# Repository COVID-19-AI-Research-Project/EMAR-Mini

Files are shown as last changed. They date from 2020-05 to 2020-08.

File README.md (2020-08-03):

# Peter Moss COVID-19 AI Research Project
## EMAR Mini Emergency Assistance Robot
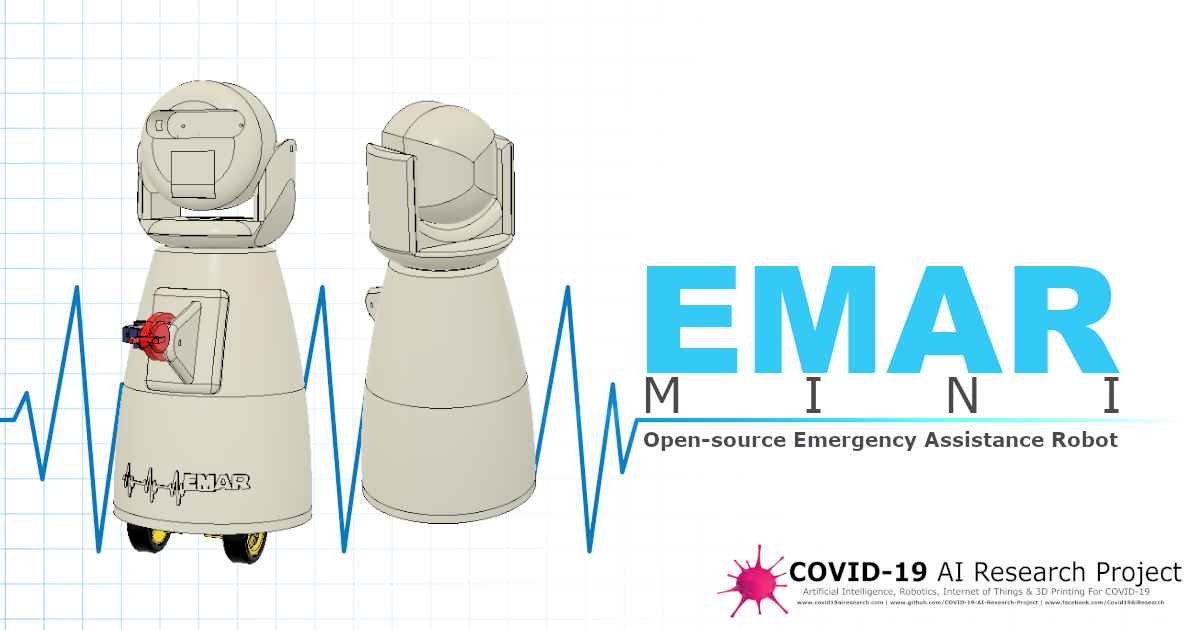
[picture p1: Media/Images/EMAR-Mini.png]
EMAR Mini Emergency Assistance Robot (https://github.com/COVID-19-AI-Research-Project/EMAR-Mini)


    

&nbsp; 

# Table Of Contents

- [Introduction](#introduction)
- [Open Technology](#open-technology)
- [Key Features](#key-features)
- [Available Features](#avialable-features)
- [About Raspberry Pi 4](#about-raspberry-pi-4)
- [About Intel® RealSense™ D415](#about-intel-realsense-d415)
- [About Intel® Neural Compute Stick 2](#about-intel-neural-compute-stick-2)
- [About ELEGOO UNO R3 Kit](#about-elegoo-uno-r3-kit)
- [About ESP8266 12F](#about-esp8266-12f)
- [Projects](#projects)
- [Contributing](#contributing)
    - [Contributors](#contributors)
- [Versioning](#versioning)
- [License](#license)
- [Bugs/Issues](#bugs-issues)

&nbsp;

# Introduction

EMAR Mini Emergency Assistance Robot

**EMAR Mini** is a minature version of EMAR, an open-source Emergency Robot Assistant to assist doctors, nurses and hospital staff during the COVID-19 pandemic, and similar situations we may face in the future.

The idea for this open-source tele-operated robot came as I was sat in room in a hospital surrounded by people with COVID-19 as a potential COVID-19 Pneumonia patient. The doctors, nurses and other teams were in among us for the whole 12 hours or more I was in the hospital.

Some of the common things I saw was nurses & doctors calling patients, giving paracetamol, taking temperatures, adjusting masks and blankets. Every time one of the medical staff had to do one of these tasks they were putting themselves in danger of catching COVID-19.

Each of these tasks can be carried out by tele-operated robots, so this is where the idea for EMAR came from.   

EMAR Mini will be our official demonstration robot as it is smaller and more portable, though has obvious restrictions compared to EMAR. EMAR Mini does not have the full capabilities of EMAR.

__This project is a work in progress, however our plan is to work with a local medical/health center or hospital to do a pilot project with EMAR (Large).__

&nbsp;

# Open Technology
- **Open Software** 
    - EMAR Mini's software is entirely open-source.
- **Open STLS** 
    - The STL files required to print EMAR are open-source.

&nbsp;

# Key Features

Below are the features that will be available in the completed 

- **HIAS Network Device:** EMAR is a device on the HIAS network, allowing machine to machine/machine to application communication.

- **HIAS UI Plugin:** Integration with the HIAS UI.

- **3D printed:** EMAR's shell is 3D printed.

- **Tele-Operated:** Remotely operated using the HIAS UI, voice control & remote control.

- **Real-Time Depth Sensing:**  Uses Intel® RealSense™ D415 camera and streams depth frames to a local server, used by HIAS to allow users to see realtime stream of depth sensors.

- **Real-Time Camera Stream:** Uses Intel® RealSense™ D415 camera and streams camera frames to a local server.

- **Object Detection:** Uses Intel Neural Computer Stick 2 to provide object recognition on the Realsense D415 camera stream.

- **Remote Control:** Uses ELEGOO Uno R3 kit with their IR Receiver Module and Remote Control to provide easy remote control of EMAR Mini.

- **Real-Time 2 Way Audio Communication:** Audio is sent from HIAS and other applications to EMAR Mini and vice versa. This feature is to provide medical teams the ability to communicate with patients in real-time whilst seeing them via the real-time camera stream.

- **Thermal Sensing:** A thermal camera is used to take patient's temperatures safely.

&nbsp;

# Available Features

As mentioned the project is a work in progress. Below you will find the currently available features.

- V1 of the 3D printed files are now available.

- V1 of the HIAS EMAR/EMAR Mini UI is now available in the [HIAS server](https://github.com/LeukemiaAiResearch/HIAS "HIAS server") project. This system allows tele-operation of EMAR Mini and viewing the real-time streams.

- HIAS tele-operation for the following:
    - Panning the head.
    - Moving the two arm pieces.

- Real-time depth sensing and stream.

- Real-time camera stream, object detection and object distance measurements.

&nbsp;

# About Raspberry Pi 4

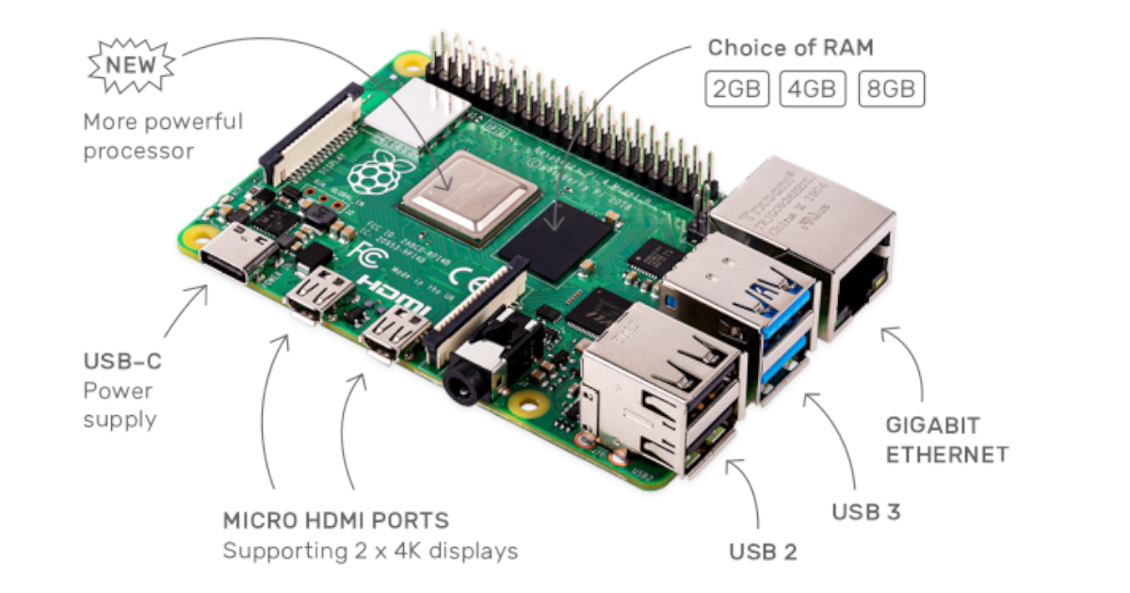
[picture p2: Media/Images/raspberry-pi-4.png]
Raspberry Pi 4 (https://www.raspberrypi.org/products/raspberry-pi-4-model-b/)


The [Rapsberry Pi 4](https://www.raspberrypi.org/products/raspberry-pi-4-model-b/ "Rapsberry Pi 4") is the latest model in the Raspberry Pi family. The new model is more energey efficient, provides Gigabit Ethernet/WiFi/Bluetooth and has USB3. You can choose from 2GB, 4GB, or 8GB ram depending on the requirements of your project. 

In this project we use the 2GB ram model and the [Rapsberry Pi OS (Buster)](https://www.raspberrypi.org/downloads/raspberry-pi-os/ "Rapsberry Pi OS (Buster)"). The RPI4 device homes all of the software required to run EMAR Mini.

&nbsp;

# About Intel® RealSense™ D415

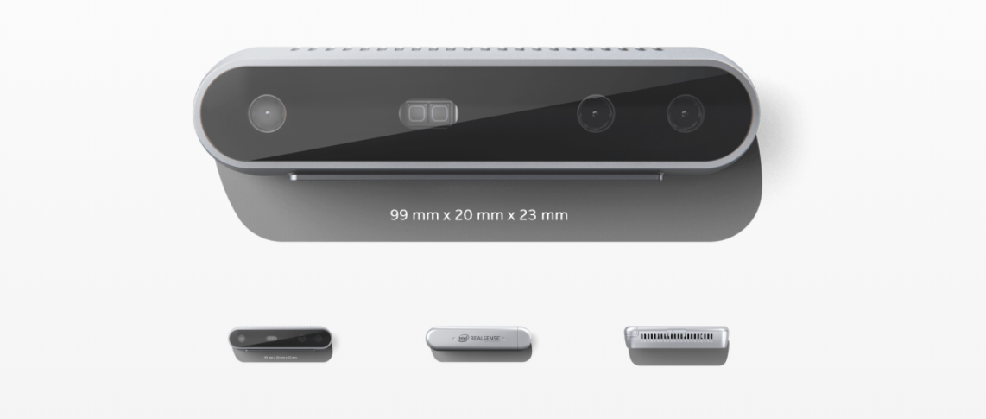
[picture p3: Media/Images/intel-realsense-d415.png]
Intel® RealSense™ D415 (https://www.intelrealsense.com/depth-camera-d415/)


The [Intel® RealSense™ D415](https://www.intelrealsense.com/depth-camera-d415/ "Intel® RealSense™ D415") has a standard field of view well suited for high accuracy applications such as 3D scanning. With a rolling shutter on the depth sensor, the D415 offers our highest depth quality per degree. 

In this project we use the D415 device to provide real-time depth and camera streams, as well as providing the depth measurements to allow distance measuring of objects seen by the camera.

&nbsp;

# About Intel® Neural Compute Stick 2

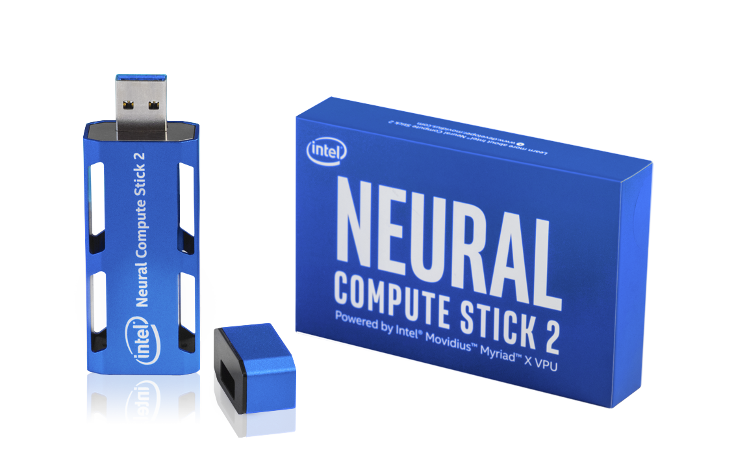
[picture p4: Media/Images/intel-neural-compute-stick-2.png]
Intel® Neural Compute Stick 2 (https://store.intelrealsense.com/buy-intel-neural-compute-stick-2.html)


The [Intel® Neural Compute Stick 2](https://store.intelrealsense.com/buy-intel-neural-compute-stick-2.html "Intel® Neural Compute Stick 2") (NCS2) is a USB plug & play AI device for deep learning inference at the edge. The Intel® NCS2 is built on the Intel® Movidius™ Myriad™ X VPU featuring 16 programmable shave cores and a dedicated neural compute engine for hardware acceleration of deep neural network inferences. 

In this project we use the NCS2 device to provide real-time object detection on the D415 real-time camera stream.

&nbsp;

# About ELEGOO UNO R3 Kit

ELEGOO UNO R3 EMAR Mini Remote Control (https://www.amazon.es/ELEGOO-Iniciaci%C3%B3n-Alimentaci%C3%B3n-Servomotor-Desarrollo/dp/B01MXGST4I)

 The [ELEGOO UNO Project Super Starter Kit](https://www.amazon.es/ELEGOO-Iniciaci%C3%B3n-Alimentaci%C3%B3n-Servomotor-Desarrollo/dp/B01MXGST4I "ELEGOO UNO Project Super Starter Kit") is an IoT development kit that provides an **ELEGOO UNO R3** board which is compatible with Arduino IDE, and a range of IoT sensors and actuators for fast prototyping of IoT projects. 

 In this project we use the **IR Receiver Module** and **Remote Control** to provide real-time control of EMAR Mini. 

 **We would like to thank ELEGOO for sponsoring us with this kit. This will be one of the medical projects we are building that will use this kit.**

 # About ESP8266 12F

 The [ESP8266 12F](https://www.espressif.com/en/products/socs/esp8266/overview "ESP8266 12F") a 2016 chip from the ESP8266 family. The chip has 1 MiB of built-in flash, allowing the building of single-chip devices capable of connecting to Wi-Fi.

 We use the ESP8266 12F to connect the ELEGOO UNO R3 to the iotJumpWay allowing communication between the remote control and EMAR Mini. The ELEGOO UNO R3 communicates with the ESP8266 via serial communication which sends commands to EMAR Mini via the iotJumpWay

&nbsp;

## Projects

Below you will find all EMAR Mini projects, including the STLs for 3D printing, the Raspberry Pi 4 version, and the remote control.

**PLEASE NOTE: This project requires a functioning installation of the [HIAS server](https://github.com/LeukemiaAiResearch/HIAS "HIAS server"). Follow the [HIAS server installation guide](https://github.com/LeukemiaAiResearch/HIAS/blob/master/Documentation/Installation/Installation.md "HIAS server installation guide") before beginning these tutorials.**

| ID | GUIDE | INFORMATION | AUTHOR | Status |
| ----- | ----- | --- | --- | --- |
| 1 | [STLs For 3D Printing](Projects/STLs "STLs For 3D Printing") | V1 of the open-source 3D printed files for EMAR Mini. |  [Jose Mario Garza](https://www.leukemiaresearchassociation.ai/team/jose-mario-garza "Jose Mario Garza") | V1 Complete | 
| 2 | [Raspberry Pi 4](Projects/RPI4 "Raspberry Pi 4") | V1 of the Raspberry Pi 4 hardware and software setup required for EMAR Mini. |  [Adam Milton-Barker](https://www.leukemiaresearchassociation.ai.com/team/adam-milton-barker "Adam Milton-Barker") | V1 Complete | 
| 3 | [ELEGOO UNO R3 Remote Control](Projects/Remote-Control "ELEGOO UNO R3 Remote Control") | An IoT connected remote control that can control EMAR Mini. |  [Adam Milton-Barker](https://www.leukemiaresearchassociation.ai.com/team/adam-milton-barker "Adam Milton-Barker") | Complete | 

&nbsp;

# Contributing

The Peter Moss Acute COVID-19 AI Research project encourages and welcomes code contributions, bug fixes and enhancements from the Github.

Please read the [CONTRIBUTING](CONTRIBUTING.md "CONTRIBUTING") document for a full guide to forking your repositories and submitting your pull requests. You will also find information about your code of conduct on this page.

## Contributors

- [Adam Milton-Barker](https://www.leukemiaresearchassociation.ai/team/adam-milton-barker "Adam Milton-Barker") - [Asociacion De Investigation En Inteligencia Artificial Para La Leucemia Peter Moss](https://www.leukemiaresearchassociation.ai "Asociacion De Investigation En Inteligencia Artificial Para La Leucemia Peter Moss") President & Lead Developer, Sabadell, Spain

- [Jose Mario Garza](https://www.leukemiaresearchassociation.ai/team/jose-mario-garza "Jose Mario Garza") - [Asociacion De Investigation En Inteligencia Artificial Para La Leucemia Peter Moss](https://www.leukemiaresearchassociation.ai "Asociacion De Investigation En Inteligencia Artificial Para La Leucemia Peter Moss") 3D Designer/Printer, Mexico

&nbsp;

# Versioning

We use SemVer for versioning. For the versions available, see [Releases](releases "Releases").

&nbsp;

# License

This project is licensed under the **MIT License** - see the [LICENSE](LICENSE "LICENSE") file for details.

&nbsp;

# Bugs/Issues

We use the [repo issues](issues "repo issues") to track bugs and general requests related to using this project. See [CONTRIBUTING](CONTRIBUTING.md "CONTRIBUTING") for more info on how to submit bugs, feature requests and proposals.

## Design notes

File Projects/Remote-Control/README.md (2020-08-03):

# Peter Moss COVID-19 AI Research Project
## EMAR Mini Emergency Assistance Robot
### ELEGOO UNO R3 Remote Control
EMAR Mini Emergency Assistance Robot (https://github.com/COVID-19-AI-Research-Project/EMAR-Mini)

&nbsp; 

# Table Of Contents

- [Introduction](#introduction)
- [Installation](#installation)
- [Start The Software](#start-the-software)
- [Use the remote control](#use-the-remote-control)
- [Contributing](#contributing)
    - [Contributors](#contributors)
- [Versioning](#versioning)
- [License](#license)
- [Bugs/Issues](#bugs-issues)

&nbsp;

# Introduction

Remote Control

 In this project we use the **ELEGOO UNO R3** with their **IR Receiver Module** and **Remote Control** from their [ELEGOO UNO Project Super Starter Kit](https://www.amazon.es/ELEGOO-Iniciaci%C3%B3n-Alimentaci%C3%B3n-Servomotor-Desarrollo/dp/B01MXGST4I "ELEGOO UNO Project Super Starter Kit") to provide real-time control of EMAR Mini. 

 **We would like to thank ELEGOO for sponsoring us with this kit. This will be one of the medical projects we are building that will use this kit.**

 For WiFi connectivity we use the ESP8266 12f and serial communication to receive the IR commands from the ELEGOO board.

&nbsp;

# Installation

Please follow the [Installation Guide](Documentation/Installation.md) to install the EMAR Mini software and hardware.

&nbsp;

# Use the remote control

Now you are all setup, just plug your ELEGOO UNO R3 board into the mains, make sure EMAR Mini is alive, point the remote at the IR sensor and use the following buttons to control EMAR Mini.

- Fast Forward (>>) = Pan head right
- Rewind (<<) - Pan head left
- Pause = Pan head to center

- 2 = Arm section 1 up
- 5 = Arm section 1 down
- Volume Up (^) = Arm section 2 up
- Volume Down = Arm section 2 down

These actions should happen in near real-time. 

# To Be Continued

HIAS EMAR UI

We are working on modifications to the 3D printed files and the additional functionality such as head tilt and wheels. Keep an eye on our page for updates to this repository.

&nbsp;

# Contributing

The Peter Moss Acute COVID-19 AI Research project encourages and welcomes code contributions, bug fixes and enhancements from the Github.

Please read the [CONTRIBUTING](../../CONTRIBUTING.md "CONTRIBUTING") document for a full guide to forking your repositories and submitting your pull requests. You will also find information about your code of conduct on this page.

## Contributors

- [Adam Milton-Barker](https://www.leukemiaresearchassociation.ai/team/adam-milton-barker "Adam Milton-Barker") - [Asociacion De Investigation En Inteligencia Artificial Para La Leucemia Peter Moss](https://www.leukemiaresearchassociation.ai "Asociacion De Investigation En Inteligencia Artificial Para La Leucemia Peter Moss") President & Lead Developer, Sabadell, Spain

&nbsp;

# Versioning

We use SemVer for versioning. For the versions available, see [Releases](../../releases "Releases").

&nbsp;

# License

This project is licensed under the **MIT License** - see the [LICENSE](../../LICENSE "LICENSE") file for details.

&nbsp;

# Bugs/Issues

We use the [repo issues](../../issues "repo issues") to track bugs and general requests related to using this project. See [CONTRIBUTING](../../CONTRIBUTING.md "CONTRIBUTING") for more info on how to submit bugs, feature requests and proposals.

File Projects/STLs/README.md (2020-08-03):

# Peter Moss COVID-19 AI Research Project
## EMAR Mini Emergency Assistance Robot
### STLs For 3D Printing
EMAR Mini Emergency Assistance Robot (https://github.com/COVID-19-AI-Research-Project/EMAR-Mini)

&nbsp; 

# Table Of Contents

- [Introduction](#introduction)
- [Prerequisites](#prerequisites)
  - [Clone the repository](#clone-the-repository)
      - [Developer Forks](#developer-forks)
- [Start Printing](#start-printing)
- [Contributing](#contributing)
    - [Contributors](#contributors)
- [Versioning](#versioning)
- [License](#license)
- [Bugs/Issues](#bugs-issues)

&nbsp;

# Introduction

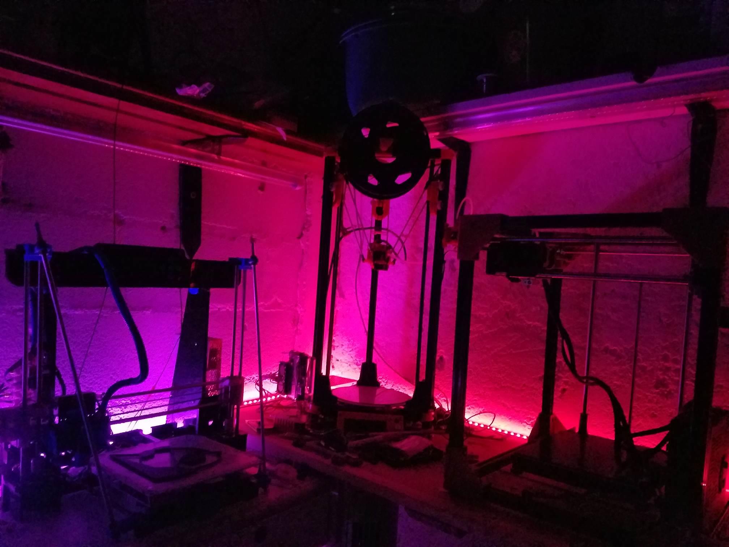
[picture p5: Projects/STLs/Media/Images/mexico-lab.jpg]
Mexico Lab


This tutorial will prepare you for printing your very on EMAR Mini V1. 
The STLs provided have been created by team member [Jose Mario Garza](https://www.leukemiaresearchassociation.ai/team/jose-mario-garza "Jose Mario Garza"), he also printed our version of EMAR Mini in his lab in Mexico.

__This project is a work in progress, we are in the process of modifying the STLs to allow for full functionality.__

&nbsp;

# Prerequisites

Before you can print your EMAR Mini V1, there are some prerequisites.

## Clone the repository

Clone the [EMAR-Mini](https://github.com/COVID-19-AI-Research-Project/EMAR-Mini " EMAR-Mini") repository from the [Peter Moss COVID-19 AI Research](https://github.com/COVID-19-AI-Research-Project "Peter Moss COVID-19 AI Research") Github Organization.

To clone the repository and install the COVID-19 Tensorflow DenseNet Classifier For Raspberry Pi 4, make sure you have Git installed. Now navigate to the home directory on your device using terminal/commandline, and then use the following command.

```
$ git clone https://github.com/COVID-19-AI-Research-Project/EMAR-Mini.git
```

Once you have used the command above you will see a directory called **EMAR-Mini** in your home directory.

```
ls
```

Using the ls command in your home directory should show you the following.

```
EMAR-Mini
```

Navigate to **COVID-19-AI-Research-Project/Projects/STLs** directory, this is your project root directory for this tutorial.

### Developer Forks

Developers from the Github community that would like to contribute to the development of this project should first create a fork, and clone that repository. For detailed information please view the [CONTRIBUTING](../../../../CONTRIBUTING.md "CONTRIBUTING") guide. You should pull the latest code from the development branch.

```
  $ git clone -b "0.5.0" https://github.com/COVID-19-AI-Research-Project/EMAR-Mini.git
```

The **-b "0.5.0"** parameter ensures you get the code from the latest master branch. Before using the below command please check our latest master branch in the button at the top of the project README.

&nbsp;

# Start Printing

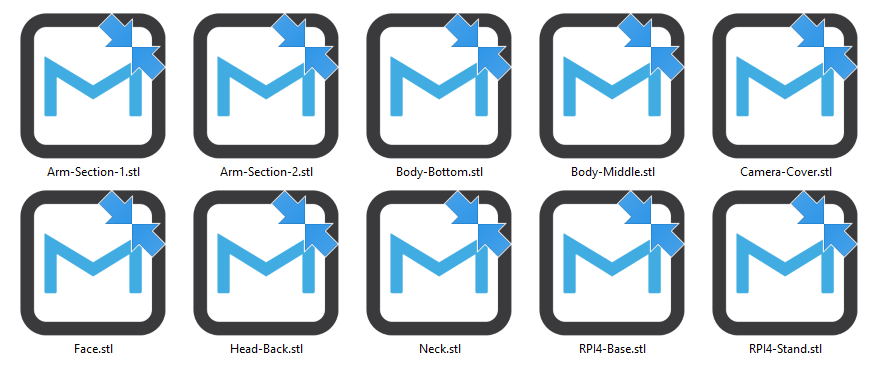
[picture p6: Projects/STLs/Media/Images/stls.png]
Start Printing


Now it is time to start printing, simply start printing the files from the **Files** folder.

&nbsp;

# Contributing

The Peter Moss Acute COVID-19 AI Research project encourages and welcomes code contributions, bug fixes and enhancements from the Github.

Please read the [CONTRIBUTING](../../CONTRIBUTING.md "CONTRIBUTING") document for a full guide to forking your repositories and submitting your pull requests. You will also find information about your code of conduct on this page.

## Contributors

- [Jose Mario Garza](https://www.leukemiaresearchassociation.ai/team/jose-mario-garza "Jose Mario Garza") - [Asociacion De Investigation En Inteligencia Artificial Para La Leucemia Peter Moss](https://www.leukemiaresearchassociation.ai "Asociacion De Investigation En Inteligencia Artificial Para La Leucemia Peter Moss") 3D Designer/Printer, Mexico

&nbsp;

# Versioning

We use SemVer for versioning. For the versions available, see [Releases](../../releases "Releases").

&nbsp;

# License

This project is licensed under the **MIT License** - see the [LICENSE](../../LICENSE "LICENSE") file for details.

&nbsp;

# Bugs/Issues

We use the [repo issues](../../issues "repo issues") to track bugs and general requests related to using this project. See [CONTRIBUTING](../../CONTRIBUTING.md "CONTRIBUTING") for more info on how to submit bugs, feature requests and proposals.

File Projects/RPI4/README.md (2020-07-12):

# Peter Moss COVID-19 AI Research Project
## EMAR Mini Emergency Assistance Robot
### Raspberry Pi 4
EMAR Mini Emergency Assistance Robot (https://github.com/COVID-19-AI-Research-Project/EMAR-Mini)

&nbsp; 

# Table Of Contents

- [Introduction](#introduction)
- [Installation](#installation)
- [Start The Software](#start-the-software)
- [HIAS EMAR UI](#hias-emar-ui)
- [To Be Continued](#to-be-continued)
- [Contributing](#contributing)
    - [Contributors](#contributors)
- [Versioning](#versioning)
- [License](#license)
- [Bugs/Issues](#bugs-issues)

&nbsp;

# Introduction

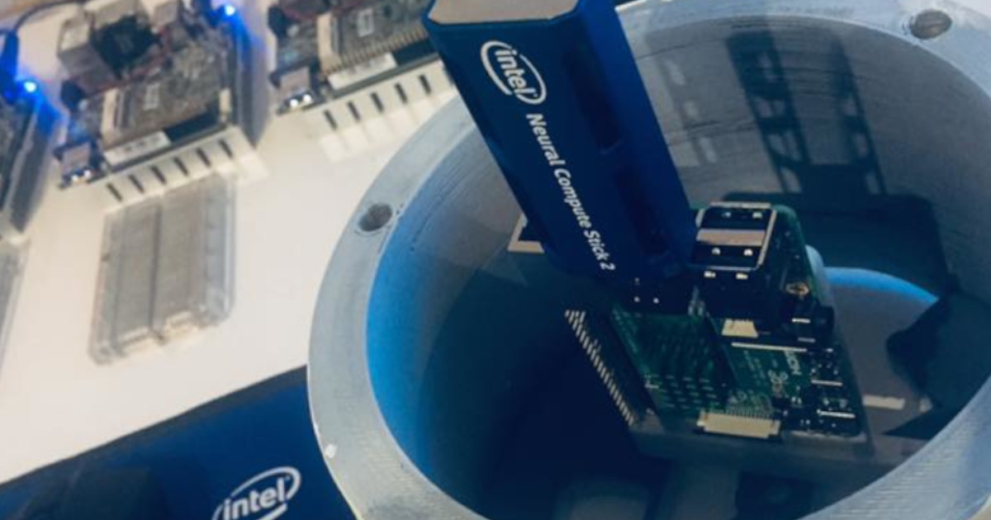
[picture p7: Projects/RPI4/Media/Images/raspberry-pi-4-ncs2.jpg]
Raspberry Pi 4


The Raspberry Pi 4 homes the EMAR Mini software and powers the Intel hardware. This guide will provide a link to the installation guide and steps to get your EMAR Mini up and running using the HIAS Server UI. 

__This project is a work in progress, we are in the process of completing for full functionality of EMAR Mini.__

&nbsp;

# Installation

Please follow the [Installation Guide](Documentation/Installation.md) to install the EMAR Mini software and hardware.

&nbsp;

# Start The Software

You now need to start the EMAR Mini software. On your Raspberry Pi navigate to your project root and issue the following command:

```
python3 EMAR.py
```

EMAR Mini will connect to your HIAS iotJumpWay broker, and start the Realsense stream and classifier.

# HIAS EMAR UI

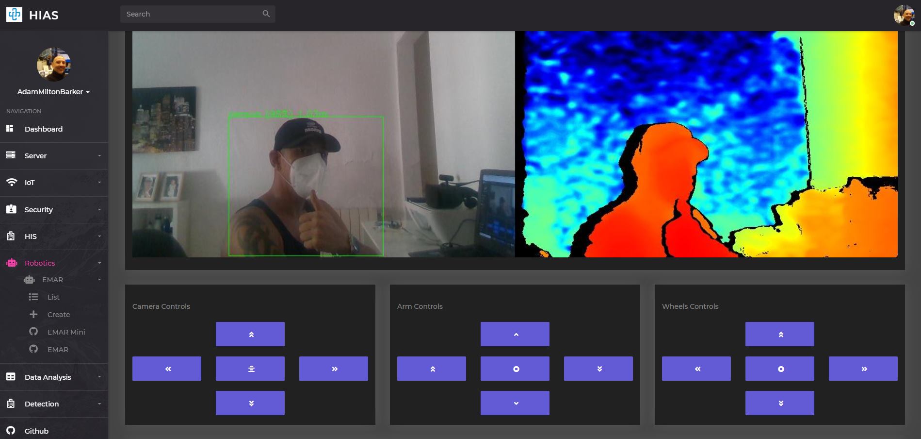
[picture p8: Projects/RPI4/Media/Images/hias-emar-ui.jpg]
HIAS EMAR UI


Now head to your HIAS Server and navigate to **Robotics->EMAR->List**, select your EMAR device and you should see your camera stream and the controls for EMAR Mini.

Available controls in this version of EMAR Mini are as follows:

- Head
  - LEFT
  - CENTER
  - RIGHT

  As you pan the head, you should see your camera stream moving in near real-time in the HIAS Server EMAR UI.

- Arm 
  - Arm section 1 UP
  - Arm section 1 DOWN
  - Arm section 2 UP
  - Arm section 2 DOWN

  In the **Arm** section, the double arrows represent arm section 1 and the single arrows represent arm section 2.

These actions should happen in near real-time, even if the controller is on the other side of the world. 

The object detection will detect any of the objects from the list in the project configuration, and will calculate the distance from EMAR Mini using the depth readings from the Intel Realsense. 

# To Be Continued

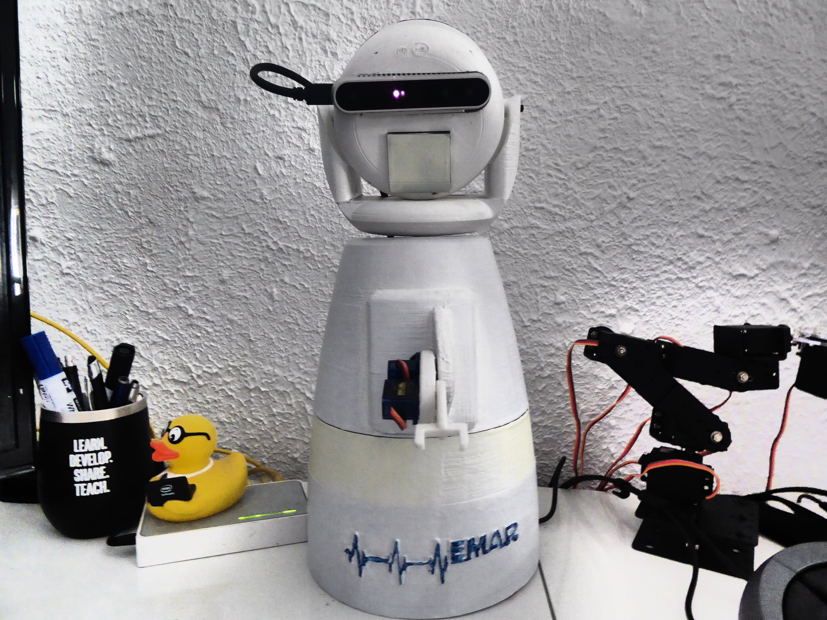
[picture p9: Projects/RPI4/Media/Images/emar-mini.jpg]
HIAS EMAR UI


We are working on modifications to the 3D printed files and the additional functionality such as head tilt and wheels. Keep an eye on our page for updates to this repository.

&nbsp;

# Contributing

The Peter Moss Acute COVID-19 AI Research project encourages and welcomes code contributions, bug fixes and enhancements from the Github.

Please read the [CONTRIBUTING](../../CONTRIBUTING.md "CONTRIBUTING") document for a full guide to forking your repositories and submitting your pull requests. You will also find information about your code of conduct on this page.

## Contributors

- [Adam Milton-Barker](https://www.leukemiaresearchassociation.ai/team/adam-milton-barker "Adam Milton-Barker") - [Asociacion De Investigation En Inteligencia Artificial Para La Leucemia Peter Moss](https://www.leukemiaresearchassociation.ai "Asociacion De Investigation En Inteligencia Artificial Para La Leucemia Peter Moss") President & Lead Developer, Sabadell, Spain

- [Jose Mario Garza](https://www.leukemiaresearchassociation.ai/team/jose-mario-garza "Jose Mario Garza") - [Asociacion De Investigation En Inteligencia Artificial Para La Leucemia Peter Moss](https://www.leukemiaresearchassociation.ai "Asociacion De Investigation En Inteligencia Artificial Para La Leucemia Peter Moss") 3D Designer/Printer, Mexico

&nbsp;

# Versioning

We use SemVer for versioning. For the versions available, see [Releases](../../releases "Releases").

&nbsp;

# License

This project is licensed under the **MIT License** - see the [LICENSE](../../LICENSE "LICENSE") file for details.

&nbsp;

# Bugs/Issues

We use the [repo issues](../../issues "repo issues") to track bugs and general requests related to using this project. See [CONTRIBUTING](../../CONTRIBUTING.md "CONTRIBUTING") for more info on how to submit bugs, feature requests and proposals.

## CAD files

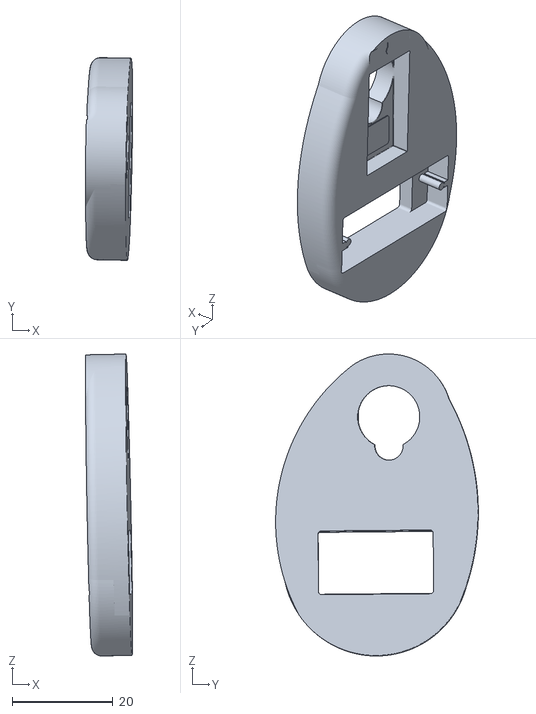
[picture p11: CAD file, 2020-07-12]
Projects/STLs/Files/Arm-Section-1.stl
9.43 x 40.3 x 60.0

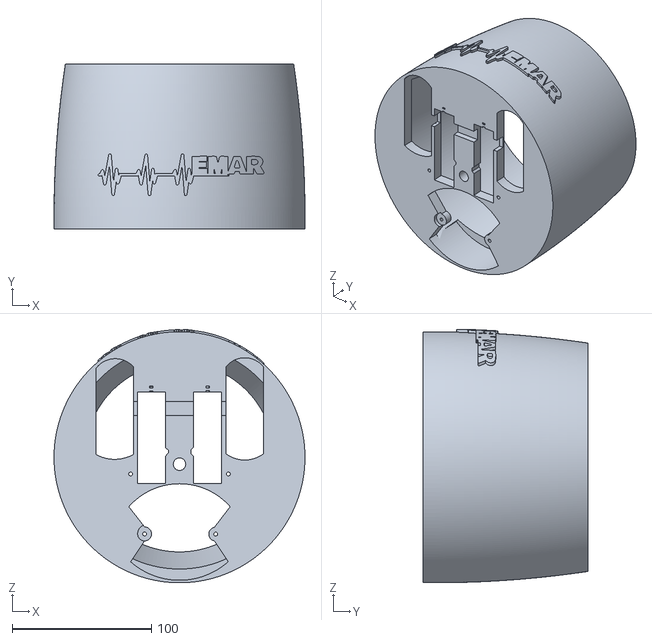
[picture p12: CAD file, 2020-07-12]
Projects/STLs/Files/Body-Bottom.stl
180.0 x 118.1 x 181.8

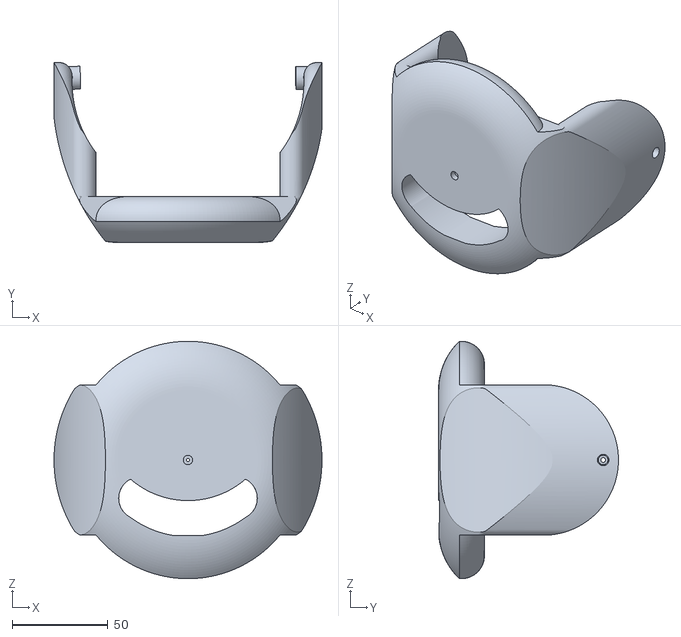
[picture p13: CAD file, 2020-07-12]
Projects/STLs/Files/Neck.stl
140.0 x 94.0 x 124.0

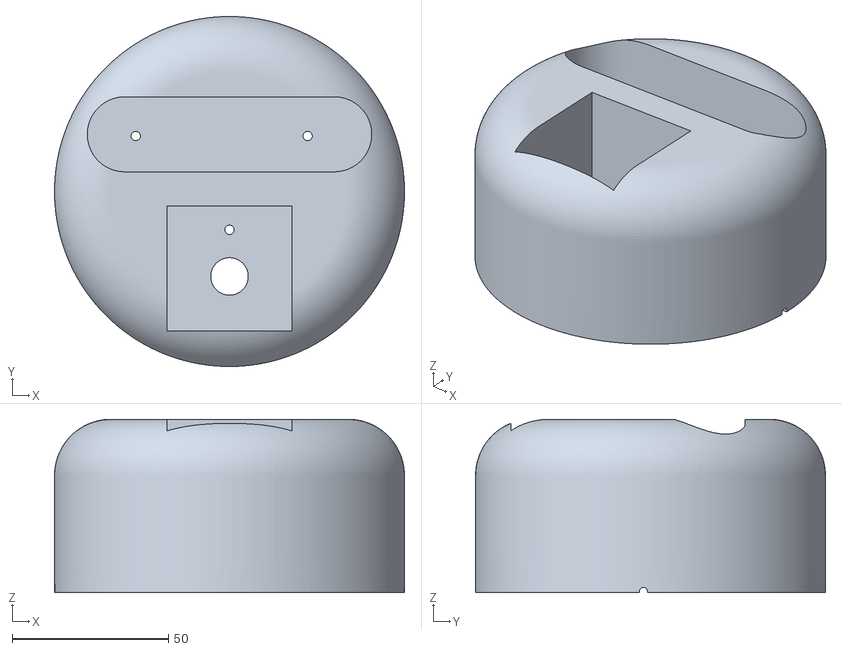
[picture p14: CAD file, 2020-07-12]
Projects/STLs/Files/Face.stl
112.0 x 112.0 x 55.5

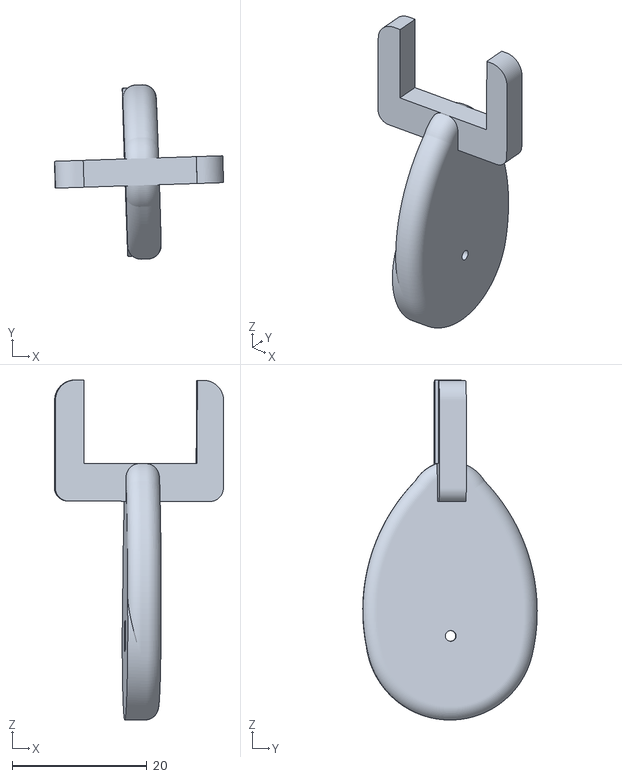
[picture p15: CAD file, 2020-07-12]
Projects/STLs/Files/Arm-Section-2.stl
25.2 x 25.9 x 50.5

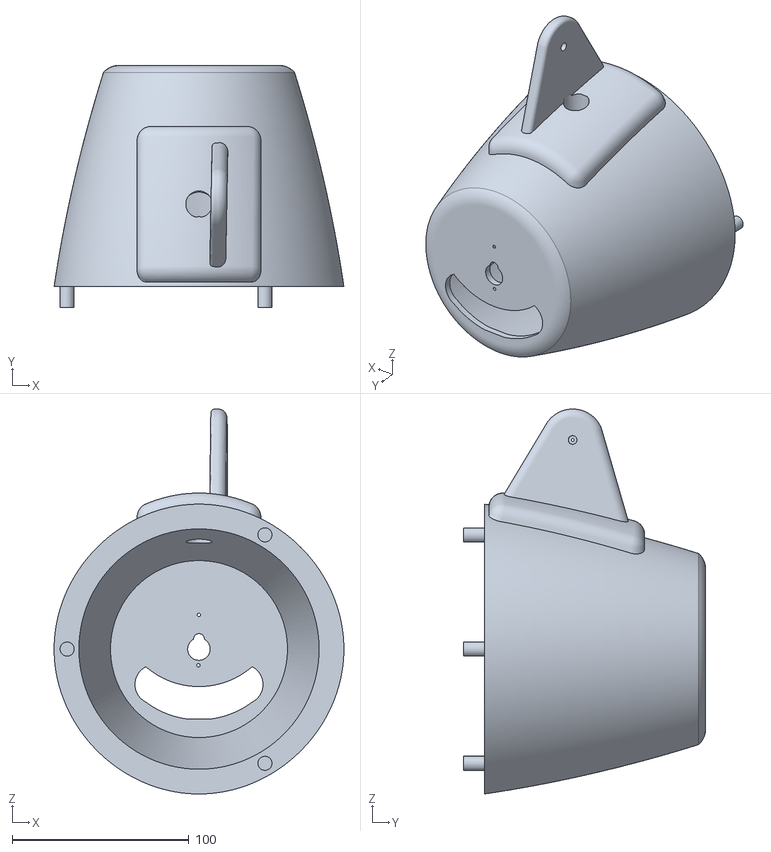
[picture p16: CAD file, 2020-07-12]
Projects/STLs/Files/Body-Middle.stl
163.8 x 137.0 x 217.6

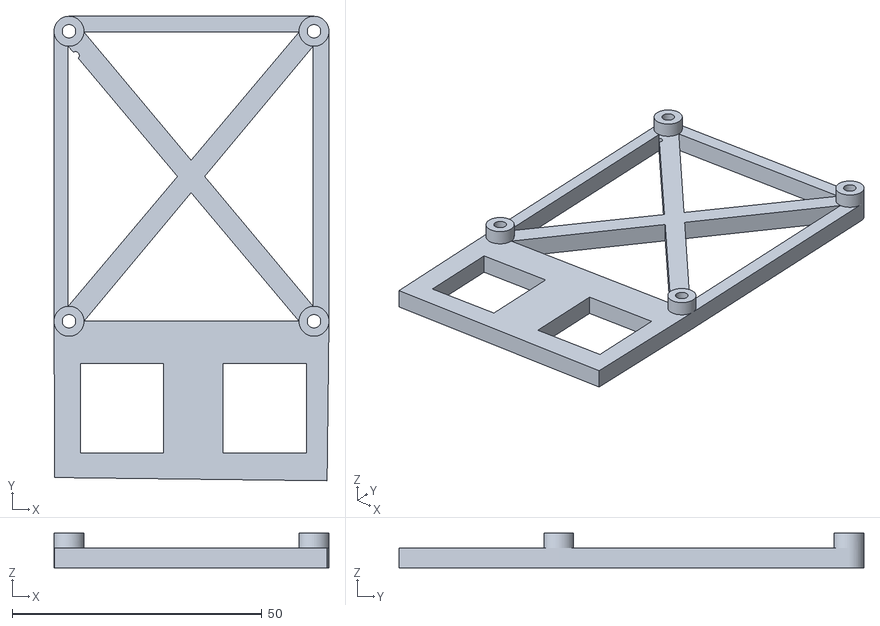
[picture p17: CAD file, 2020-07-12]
Projects/STLs/Files/RPI4-Stand.stl
55.0 x 92.9 x 7.00

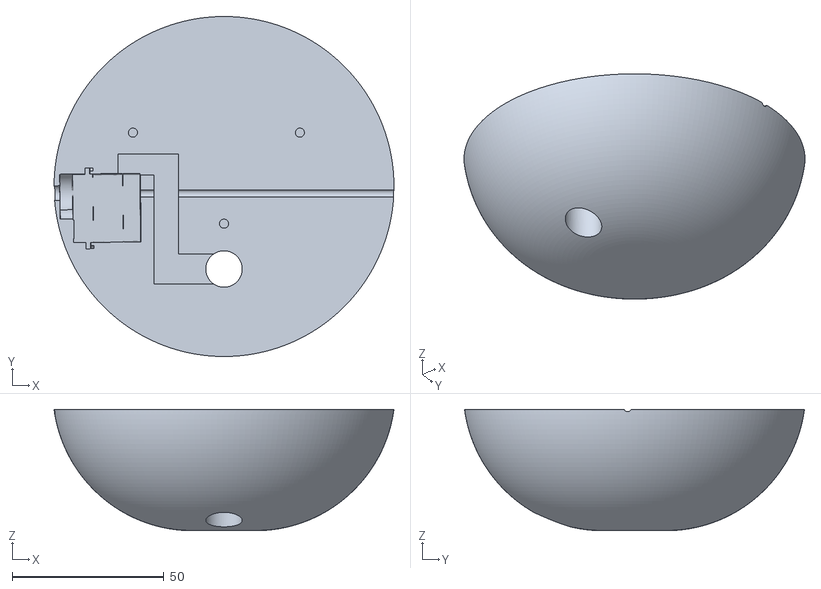
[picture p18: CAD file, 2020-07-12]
Projects/STLs/Files/Head-Back.stl
112.0 x 112.0 x 40.0

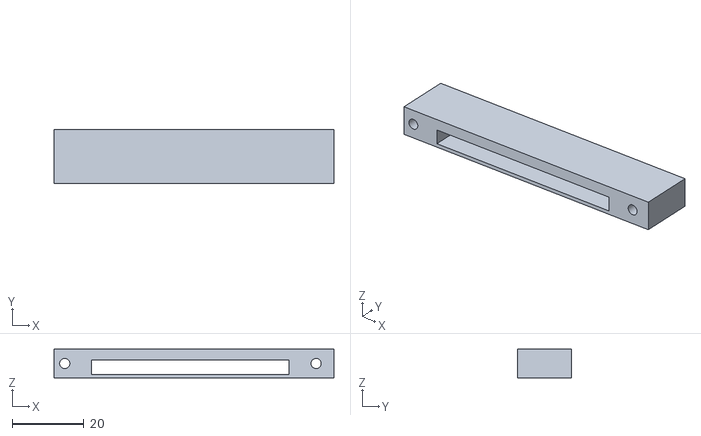
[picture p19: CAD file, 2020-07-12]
Projects/STLs/Files/RPI4-Base.stl
78.0 x 15.0 x 8.00

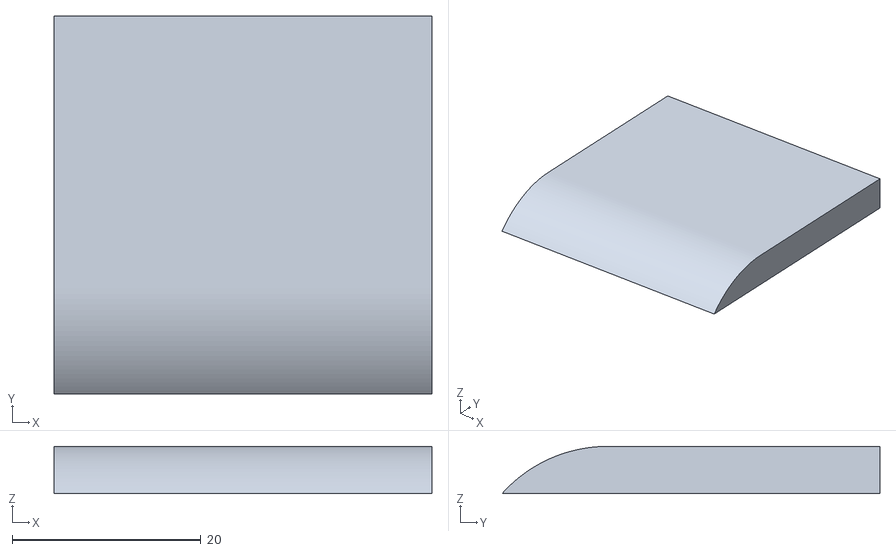
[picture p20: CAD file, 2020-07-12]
Projects/STLs/Files/Camera-Cover.stl
40.0 x 40.0 x 5.00

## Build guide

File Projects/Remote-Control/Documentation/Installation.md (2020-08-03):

# Peter Moss COVID-19 AI Research Project
## EMAR Mini Emergency Assistance Robot
EMAR Emergency Assistance Robot (https://github.com/COVID-19-Research-Project/EMAR-Mini)

&nbsp;

# Table Of Contents

- [Introduction](#introduction)
- [DISCLAIMER](#disclaimer)
- [V1 Required Hardware](#v1-required-hardware)
- [Prerequisites](#prerequisites)
    - [HIAS - Hospital Intelligent Automation System](#hias-hospital-intelligent-automation-system)
    - [STLs For 3D Printing Tutorial](#stls-for-3d-printing-tutorial)
    - [Raspberry Pi 4 Tutorial](#raspberry-pi-4-tutorial)
- [Installation](#installation)
    - [ESP8266 12F](#esp8266-12f)
    - [ELEGOO UNO R3 & Breadboard](#elegoo-uno-r3--breadboard)
    - [iotJumpWay Credentials](#iotjumpway-credentials)
    - [EMAR-RCP](#emar-rcp)
    - [EMAR-RCR](#emar-rcr)
- [Continue](#continue)
- [Contributing](#contributing)
    - [Contributors](#contributors)
- [Versioning](#versioning)
- [License](#license)
- [Bugs/Issues](#bugs-issues)

&nbsp;

# Introduction
The following guide will take you through setting up and installing [EMAR Mini Emergency Assistance Robot](https://github.com/COVID-19-Research-Project/EMAR-Mini "EMAR Mini Emergency Assistance Robot"). 

The Raspberry Pi 4 homes the EMAR Mini software and powers the Intel hardware.

&nbsp;

# DISCLAIMER

You should always be very careful when working with electronics! We will not accept responsibility for any damages done to hardware or yourself through full or partial use of this tutorial. Use this tutorial at your own risk, and take measures to ensure your own safety.

&nbsp;

# V1 Required Hardware

- 1 x ELEGOO UNO R3 Remote Control 
- 1 x ELEGOO IR Receiver Module
- 1 x Breadboard
- 1 x ESP8266
- 1 x USB to serial TTL UART Module
- 2 x Push Buttons
- 1 x 100Uf Ceramic Capacitor
- 5 x 10k Resistors
- 1 x Soldering Iron
- Solder
- Jumper wires

&nbsp;

# Prerequisites

Before you can complete this tutorial there are some prerequisites.

## HIAS - Hospital Intelligent Automation System
You will need a full installation of the [HIAS server](https://github.com/LeukemiaAiResearch/HIAS) to use the full functionality of this project. You can use this project with a 3rd party IoT broker if you like but we do not provide the documentation for that.

## STLs For 3D Printing Tutorial
You need to have completed the [STLs For 3D Printing](../../STLs "STLs For 3D Printing") tutorial and printed the EMAR Mini parts. 

## Raspberry Pi 4 Tutorial
You need to have completed the [Raspberry Pi 4](../../RPI4 "Raspberry Pi 4") tutorial and setup your EMAR Mini.

&nbsp;

# Installation
Now you will create your EMAR Mini Remote Control.

## ESP8266 12F
ESP8266 12F

First we will start with the ESP8266 12F. To start, heat up your soldering iron. Next you need to solder wires to the following pins:

- TXD0
- RXD0
- GPIO0
- GPIO2
- GPIO15
- GND
- VCC 
- RST
- EN

In addition you need to solder the capacitor bridging between GND & VCC.

You are now ready to move on to setting up your ELEGOO UNO R3 and breadboard.

## ELEGOO UNO R3 & Breadboard
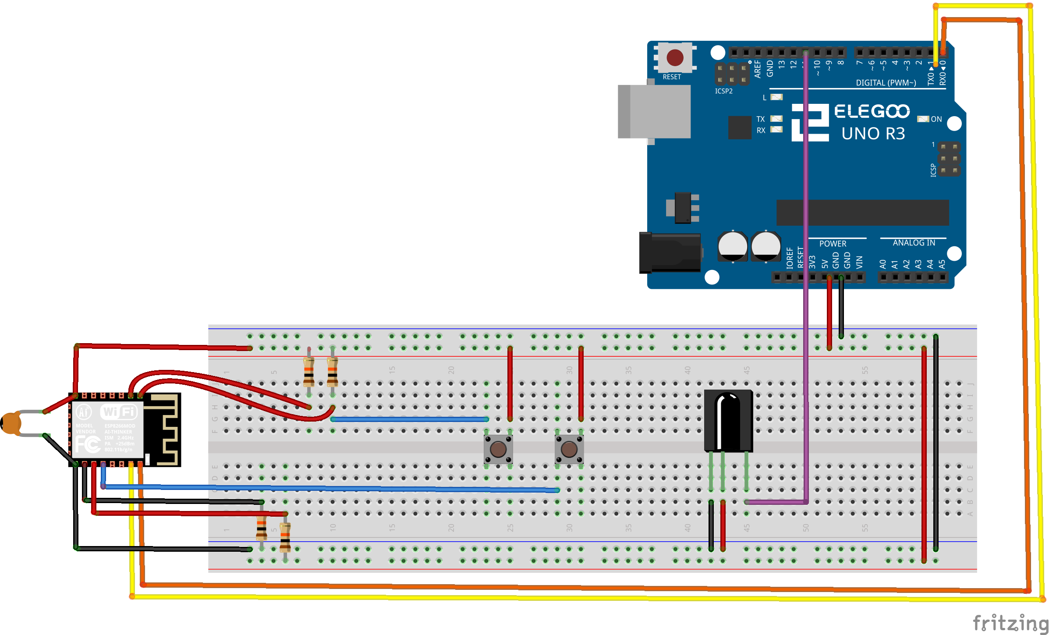
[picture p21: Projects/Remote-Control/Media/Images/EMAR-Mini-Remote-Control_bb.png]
ELEGOO UNO R3 & Breadboard


Follow the breadboard diagram above to set up your circuit. Here we are powering the ESP8266 directly from the 5V out of the ELEGOO UNO. As we are using the ESP8266, battery operation will not be possible as it will drain very quickly. You will need to plug your ELEGOO UNO into the mains using a suitable power adapter.

**WARNING: Many will advise not to power ESP8266 with 5V, however in my experience it is the only way that ESP8266 will work correctly with SSL. It is advised that the ESP8266 is not designed to run at 5V, however running at 3V you will more than likely not be able to make this project work. In all the years I have been using ESP8266, I have never had an issue with a single chip powering it with 5V. You should use 5V at your own discression**

The ESP8266 is used for WiFi communication, it connects to the iotJumpWay and waits for activity from the IR sensor, when it receives commands it sends via the iotJumpWay to EMAR Mini which allows you to control the robot using the remote control.

ELEGOO UNO R3 & Breadboard

## iotJumpWay Credentials
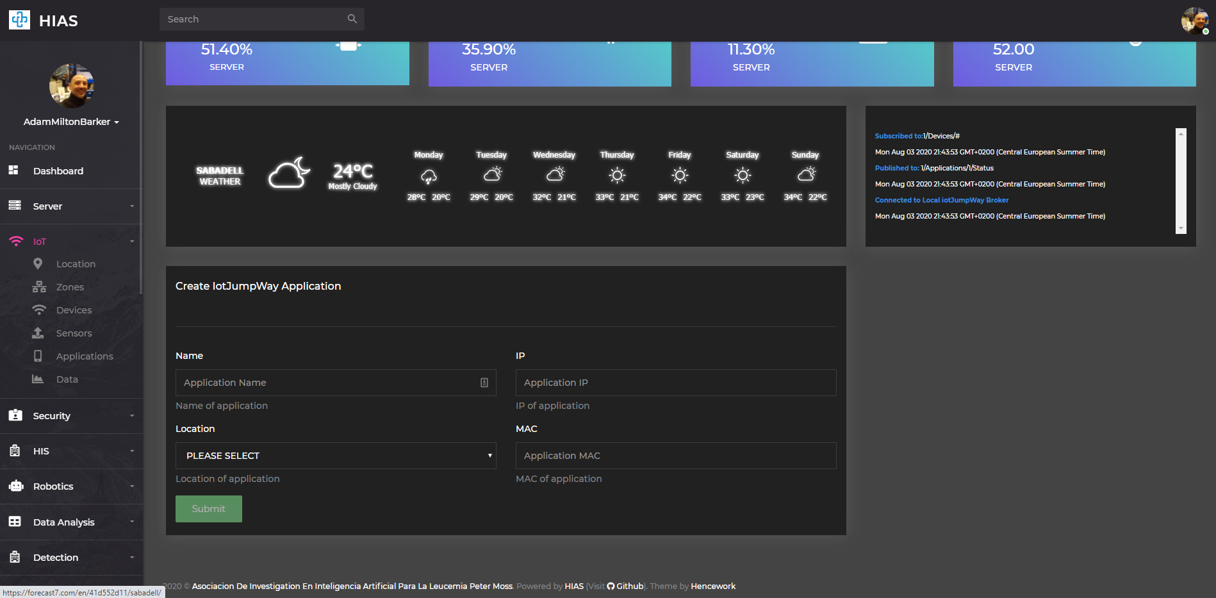
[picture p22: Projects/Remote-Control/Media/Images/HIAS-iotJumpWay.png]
iotJumpWay Credentials

Now we are going to set up the iotJumpWay Application. Head over to the HIAS UI and navigate to **IoT->Applications->Create**. Fill out the required information and click **Submit**. You will be taken to the newly created application page and will be able to access the application credentials.

## EMAR-RCP
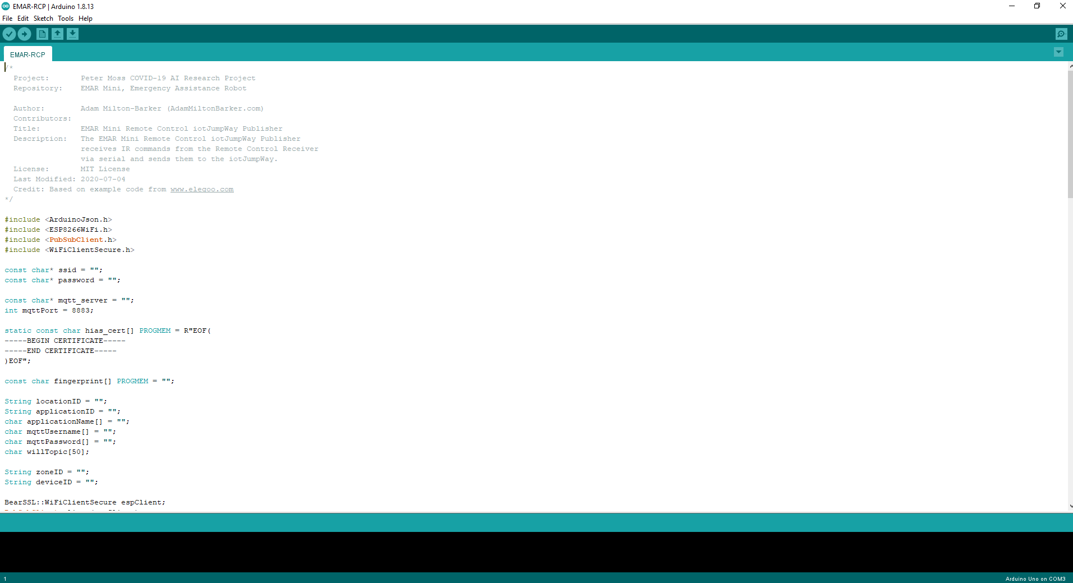
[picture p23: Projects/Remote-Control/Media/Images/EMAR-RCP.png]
EMAR-RCP


EMAR-RCP is the publisher that sends the commands to EMAR Mini via the iotJumpWay.

To begin with you need to flash the [EMAR-RCP](../EMAR-RCP/EMAR-RCP.ino "EMAR-RCP") software to the ESP8266. You will need to make sure your Arduino enviornment is set up for [ESP8266 dev](https://arduino-esp8266.readthedocs.io/en/latest/installing.html) before you continue.

In the [EMAR-RCP](../EMAR-RCP/EMAR-RCP.ino "EMAR-RCP") file, you need to need to add your SSL certificate fingerprint, your WiFi details and iotJumpWay Application credentials. 

To get your SSL certifcate fingerprint, you should click on the padlock in the browser window when you are on the HIAS UI 

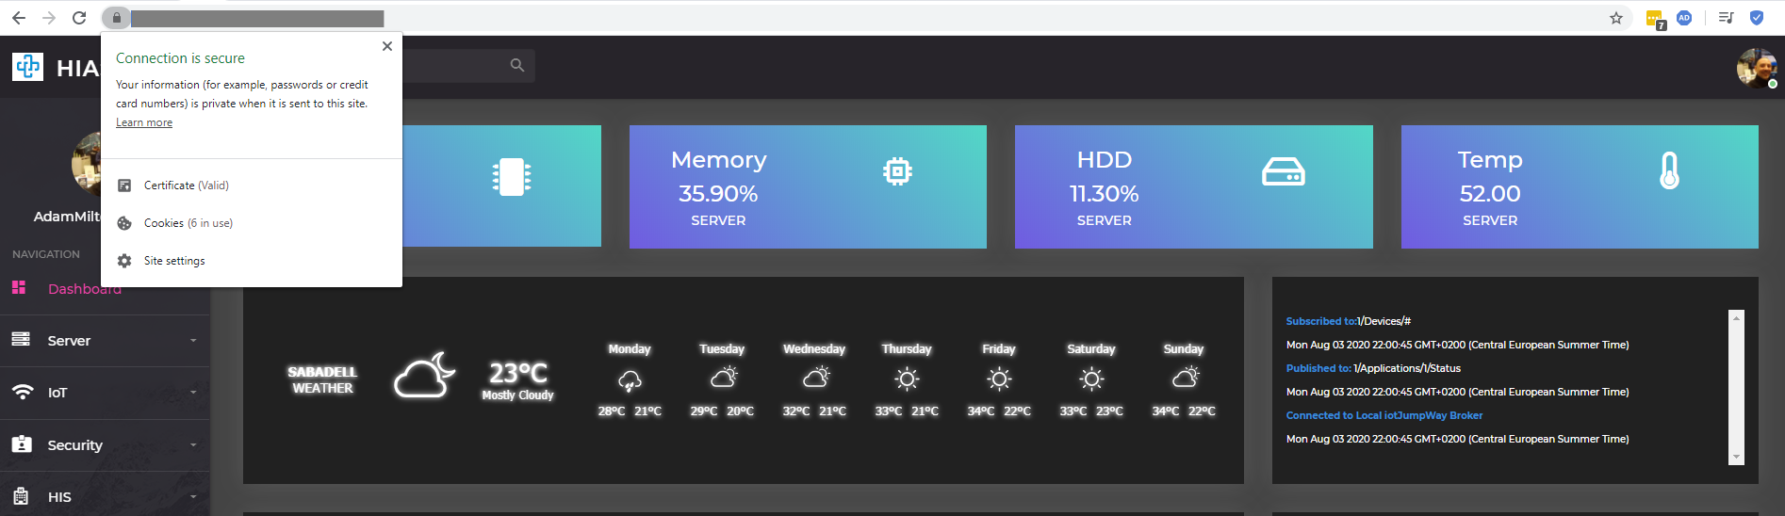
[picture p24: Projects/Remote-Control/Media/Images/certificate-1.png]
Certificate

Then click **Certificate**. This will open up a window with details about your certificate.

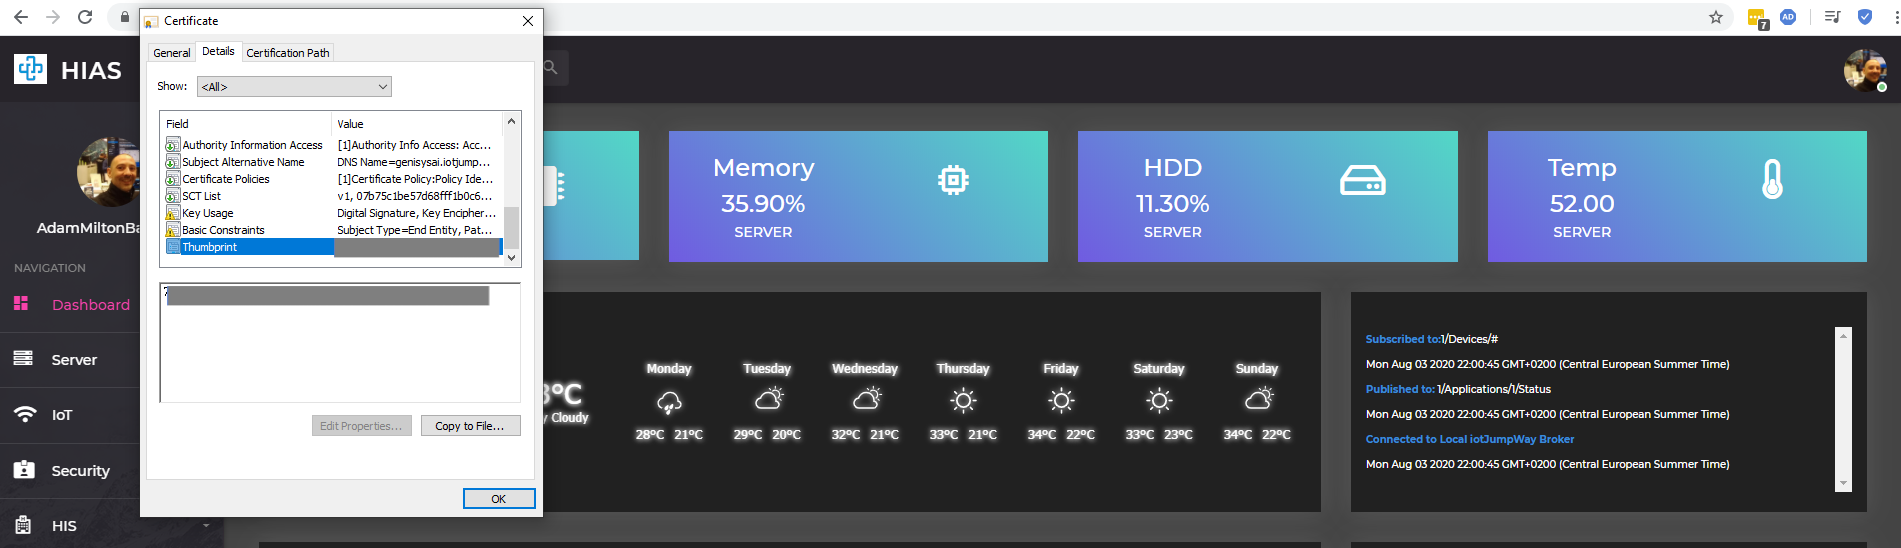
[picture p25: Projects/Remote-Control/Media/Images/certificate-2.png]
Certificate

Now click on **Details** and scroll down until you see **Thumbprint**. Click on Thumbprint and your certificate thumbprint will be displayed in the window. You should copy this thumbprint and paste it into the **fingerprint[]** setting at the top of the file (See below).

Now add your SSID and WiFi password to the settings, the URL of your HIAS server, and the iotJumpWay Application details. For the Zone and Device IDs you should use the Zone and Device ID of EMAR Mini.

```
const char fingerprint[] PROGMEM = "";

const char* ssid = "";
const char* password = "";

const char* mqtt_server = "";
int mqttPort = 8883;

String locationID = "";
String applicationID = "";
char applicationName[] = ""; 
char mqttUsername[] = ""; 
char mqttPassword[] = ""; 
char willTopic[50];

String zoneID = "";
String deviceID = "";
```
Using your chosen USB to serial TTL UART Module and the breadboard, connect RX of the serial module to the TX of the ESP8266, next connect the TX of your serial module to the RX of ESP8266 and connect the power and ground cables (Make sure you move the UNO -> ESP8266 serial connection first). 

Assuming you have the Arduino IDE set up, you can now flash the ESP8266. You will notice there are two push buttons. The one closest to the ESP8266 is for setting the ESP8266 into flash mode, the second button is for resetting the device. 

Press the upload button in Arduino IDE and straight away hold the flashing button down, after a couple of seconds push the reset button and then release both. You should see the blue LED start to flash, this means that the ESP8266 is being flashed. 

Once it has finished, the ESP8266 is ready.

## EMAR-RCR
EMAR-RCR is the remote control receiver, it waits for commands sent from the remote control and sends them via serial to the RCP script running on the ESP8266.

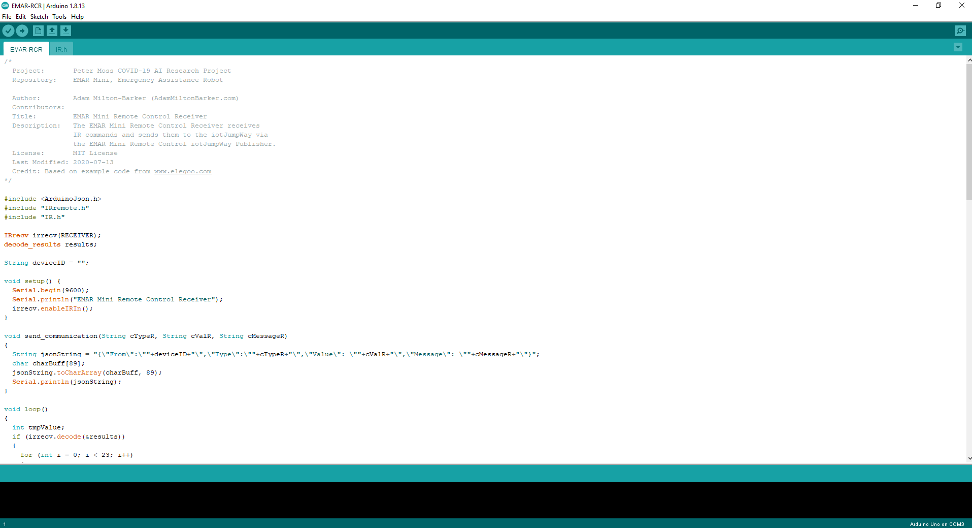
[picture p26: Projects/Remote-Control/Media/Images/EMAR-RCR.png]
EMAR-RCR


To begin with you need to flash the software to the ELEGOO UNO R3. Connect your UNO R3 to your computer.

Next you need to add the EMAR Mini Device ID to the settings at the top of the file.

```
String deviceID = "";
```

Once you flash the software to the ELEGOO UNO, you are now ready to continue. 

# Continue

Now you can continue back to the [RPI4](../../RPI4 "RPI4") tutorial to complete setup.

&nbsp;

# Contributing

The Peter Moss Acute COVID-19 AI Research project encourages and welcomes code contributions, bug fixes and enhancements from the Github.

Please read the [CONTRIBUTING](../../../CONTRIBUTING.md "CONTRIBUTING") document for a full guide to forking your repositories and submitting your pull requests. You will also find information about your code of conduct on this page.

## Contributors

- [Adam Milton-Barker](https://www.leukemiaresearchassociation.ai/team/adam-milton-barker "Adam Milton-Barker") - [Asociacion De Investigation En Inteligencia Artificial Para La Leucemia Peter Moss](https://www.leukemiaresearchassociation.ai "Asociacion De Investigation En Inteligencia Artificial Para La Leucemia Peter Moss") President & Lead Developer, Sabadell, Spain

&nbsp;

# Versioning

You use SemVer for versioning. For the versions available, see [Releases](../../../releases "Releases").

&nbsp;

# License

This project is licensed under the **MIT License** - see the [LICENSE](../../../LICENSE "LICENSE") file for details.

&nbsp;

# Bugs/Issues

You use the [repo issues](../../../issues "repo issues") to track bugs and general requests related to using this project. See [CONTRIBUTING](../../../CONTRIBUTING.md "CONTRIBUTING") for more info on how to submit bugs, feature requests and proposals.

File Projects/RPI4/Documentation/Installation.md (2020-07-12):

# Peter Moss COVID-19 AI Research Project
## EMAR Mini Emergency Assistance Robot
EMAR Emergency Assistance Robot (https://github.com/COVID-19-Research-Project/EMAR-Mini)

&nbsp;

# Table Of Contents

- [Introduction](#introduction)
- [DISCLAIMER](#disclaimer)
- [V1 Required Hardware](#v1-required-hardware)
- [Prerequisites](#prerequisites)
    - [HIAS Server](#hias-server)
    - [STLs For 3D Printing](#stls-for-3d-printing)
    - [Raspberry Pi OS Lite](#raspberry-pi-os-lite)
- [Installation](#installation)
  - [Device Security](#device-security)
    - [Remote User](#remote-user)
    - [SSH Access](#ssh-access)
    - [UFW Firewall](#ufw-firewall)
    - [Fail2Ban](#fail2ban)
  - [Python Dependencies](#python-dependencies)
  - [Create EMAR Device In HIAS](#create-emar-device-in-hias)
  - [Update Device Settings](#update-device-settings)
  - [Intel® Distribution of OpenVINO™ Toolkit](#intel-distribution-of-openvino-toolkit)
  - [Intel® RealSense™ D415](#intel-realsense-d415)
  - [Intel® Neural Compute Stick 2](#intel-neural-compute-stick-2)
  - [Connect the neck](#connect-the-neck)
  - [Assemble the head](#assemble-the-head)
  - [Connect the head to the neck](#connect-the-head-to-the-neck)
  - [Raspberry Pi 4 Stand](#raspberry-pi-4-stand)
  - [Raspberry Pi 4 Pinout](#raspberry-pi-4-pinout)
  - [Breadboard](#breadboard)
  - [Add the Intel® Neural Compute Stick 2](#add-the-intel-neural-compute-stick-2)
  - [Attach Raspberry Pi 4 Stand to EMAR Mini](#attach-raspberry-pi-4-stand-to-emar-mini)
  - [Connect the arm section](#connect-the-arm-sections)
  - [Connect servo wires to breadboard](#connect-servo-wires-to-breadboard)
  - [Connect servo wires to breadboard](#connect-servo-wires-to-breadboard)
  - [Install the breadboard](#install-the-breadboard)
  - [Install the Realsense camera](#install-the-realsense-camera)
  - [Finishing Up](#finishing-up)
- [Continue](#continue)
  
- [Contributing](#contributing)
    - [Contributors](#contributors)
- [Versioning](#versioning)
- [License](#license)
- [Bugs/Issues](#bugs-issues)

&nbsp;

# Introduction
The following guide will take you through setting up and installing [EMAR Mini Emergency Assistance Robot](https://github.com/COVID-19-Research-Project/EMAR-Mini "EMAR Mini Emergency Assistance Robot"). 

The Raspberry Pi 4 homes the EMAR Mini software and powers the Intel hardware.

&nbsp;

# DISCLAIMER

You should always be very careful when working with electronics! We will not accept responsibility for any damages done to hardware or yourself through full or partial use of this tutorial. Use this tutorial at your own risk, and take measures to ensure your own safety.

&nbsp;

# V1 Required Hardware

- 1 x Raspberry Pi 4
- 1 x Intel® RealSense™ D415
- 1 x Intel® Neural Compute Stick 2
- 1 x Breadboard
- 4 x Tower Pro SG90 Servos
- Jumper wires

&nbsp;

# Prerequisites  

## HIAS Sever
This system requires a fully functioning [HIAS server](https://github.com/LeukemiaAiResearch/HIAS "HIAS server"). Follow the [HIAS server installation guide](https://github.com/LeukemiaAiResearch/HIAS/blob/master/Documentation/Installation/Installation.md "HIAS server installation guide") to setup your HIAS server before continuing with this tutorial.

## STLs For 3D Printing

For this tutorial you will need to have already printed your EMAR Mini. Follow the [STLs For 3D Printing](../../STLs " STLs For 3D Printing") guide to complete the 3D printing part of this project.

## Raspberry Pi OS Lite

In this tutorial we will use Raspberry Pi OS Lite (Buster). First of all download the image from the [Raspberry Pi OS download page](https://www.raspberrypi.org/downloads/raspberry-pi-os/ " Raspberry Pi OS download page"), extract the image file, and write it to an SDK card. In our project we have used a 64GB SD card. 

Once you have done this, insert it in your Raspberry Pi 4, when you have logged in, use the following command to update your device and then open the Raspberry Pi configuration application. You need to expand your filesystem, setup your keyboard preferences and connect your RPI4 to your network.

```
sudo apt-get update && sudo apt-get upgrade
sudo raspi-config
```

&nbsp;

# Installation
Now you need to install the EMAR Mini hardware, software and dependencies.

## Device Security
First you will harden your device security. 

### Remote User
You will create a new user for accessing your server remotely. Use the following commands to set up a new user for your machine. Follow the instructions provided and make sure you use a secure password.
```
sudo adduser YourUsername 
```
Now grant sudo priveleges to the user:
```
usermod -aG sudo YourUsername
```
Now open a new terminal and login to your server using the new credentials you set up.
```
ssh YourNewUser@YourServerIP
```

### SSH Access
Now let's beef up server secuirty. Use the following command to set up your public and private keys. Make sure you carry out this step on your development machine, **not** on your server.

#### Tips
- Hit enter to confirm the default file. 
- Hit enter twice to skip the password (Optionalm, you can use a password if you like).
```
ssh-keygen
```
You should end up with a screen like this:
```
Generating public/private rsa key pair.
Enter file in which to save the key (/home/genisys/.ssh/id_rsa): 
Enter passphrase (empty for no passphrase): 
Enter same passphrase again: 
Your identification has been saved in /home/genisys/.ssh/id_rsa.
Your public key has been saved in /home/genisys/.ssh/id_rsa.pub.
The key fingerprint is:
SHA256:5BYJMomxATmanduT3/d1CPKaFm+pGEIqpJJ5Z3zXCPM genisys@genisyslprt
The key's randomart image is:
+---[RSA 2048]----+
|.oooo..          |
|o .o.o . .       |
|.+..    +        |
|o o    o .       |
|  .o .+ S . .    |
| =..+o = o.o . . |
|= o =oo.E .o..o .|
|.. + ..o.ooo+. . |
|        .o++.    |
+----[SHA256]-----+
```
Now you are going to copy your key to the server: 
```
ssh-copy-id YourNewUser@YourServerIP
```
Once you enter your password for the new user account, your key will be saved on the server. Now try and login to the server again in a new terminal, you should log straight in without having to enter a password.
```
ssh YourNewUser@YourServerIP
```
Finally you will turn off password authentication for login. Use the following command to edit the ssh configuration.
```
sudo nano /etc/ssh/sshd_config
```
Change the following:
```
#PasswordAuthentication yes
```
To:
```
PasswordAuthentication no
```
Then restart ssh:
```
sudo systemctl restart ssh
```
_If you are using ssh to do the above steps keep your current terminal connected._ Open a new terminal, attempt to login to your server. If you can login then the above steps were successful. 

The remainder of this tutorial assumes you are logged into your device. From your development machine, connect to your device using ssh or open your local terminal if working directly on the machine.

```
ssh YourUser@YourServerIP
```
### UFW Firewall
Now you will set up your firewall:

```
sudo ufw enable
sudo ufw disable
```
Now open the required ports, these ports will be open on your server, but are not open to the outside world:
```
sudo ufw allow 22
sudo ufw allow OpenSSH
```
Finally start and check the status:
```
sudo ufw enable
sudo ufw status
```
You should see the following:
```
Status: active

To                         Action      From
--                         ------      ----
OpenSSH                    ALLOW       Anywhere
22                         ALLOW       Anywhere
OpenSSH (v6)               ALLOW       Anywhere (v6)
22 (v6)                    ALLOW       Anywhere (v6)
```

### Fail2Ban
Fail2Ban adds an additional layer of security, by scanning server logs and looking for unusal activity. Fail2Ban is configured to work with IPTables by default, so we will do some reconfiguration to make it work with our firewall, UFW.

```
sudo apt install fail2ban
sudo mv /etc/fail2ban/jail.conf /etc/fail2ban/jail.local
sudo rm /etc/fail2ban/action.d/ufw.conf
sudo touch /etc/fail2ban/action.d/ufw.conf
echo "[Definition]" | sudo tee -a /etc/fail2ban/action.d/ufw.conf
echo "  enabled  = true" | sudo tee -a /etc/fail2ban/action.d/ufw.conf
echo "  actionstart =" | sudo tee -a /etc/fail2ban/action.d/ufw.conf
echo "  actionstop =" | sudo tee -a /etc/fail2ban/action.d/ufw.conf
echo "  actioncheck =" | sudo tee -a /etc/fail2ban/action.d/ufw.conf
echo "  actionban = ufw insert 1 deny from <ip> to any" | sudo tee -a /etc/fail2ban/action.d/ufw.conf
echo "  actionunban = ufw delete deny from <ip> to any" | sudo tee -a /etc/fail2ban/action.d/ufw.conf
sudo nano /etc/fail2ban/action.d/ufw.conf
sudo sed -i -- "s#banaction = iptables-multiport#banaction = ufw#g" /etc/fail2ban/jail.local
sudo nano /etc/fail2ban/jail.local
sudo fail2ban-client restart
sudo fail2ban-client status
```
You should see the following:
```
Shutdown successful
Server ready
```
```
Status
|- Number of jail:      1
`- Jail list:   sshd
```

## Python Dependencies

```
sudo apt install python3-pip
sudo pip3 install geolocation
sudo pip3 install paho-mqtt
sudo pip3 install psutil
sudo pip3 install numpy
sudo pip3 install requests
sudo pip3 install zmq
```

## Create EMAR Device In HIAS

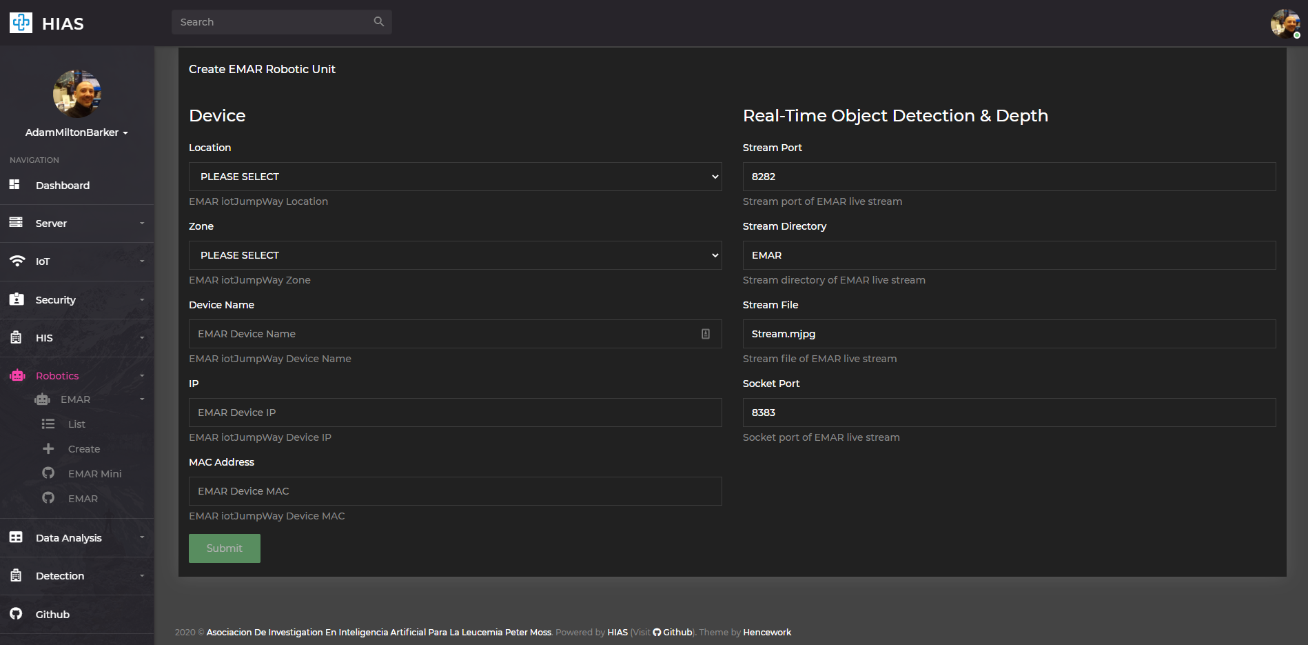
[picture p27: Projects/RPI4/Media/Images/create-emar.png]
Create EMAR Device In HIAS


Head to your HIAS Server and navigate to **Robotics->EMAR->Create**. In the **Device** settings, select your desired iotJumpWay Location and Zone, a name for your EMAR device, the IP and MAC address of your Raspberry Pi. The **Real-Time Object Detection & Depth** settings can be left with the default settings. If you modify the ports and the directory name you need to change these when updating the **HIAS Server Proxy** settings below. 

## HIAS Server Proxy

You need to update the HIAS Server Proxy settings so that the __proxy_pass__ can correctly redirect traffic to your Raspberry Pi.

To do this you need to edit the NGINX configuration. Use the following command on your HIAS server to edit the file with Nano:

```
sudo nano /etc/nginx/sites-available/default
```

Towards the top of the file you will find the settings that control the proxy for EMAR/EMAR Mini. You need to change **###.###.#.##** to the IP address of your Raspberry Pi.

If you changed the Stream Port, Stream Directory or Socket Port settings in the HIAS EMAR UI, you need to update these here also. 

```
location ~* ^/Robotics/EMAR/Live/(.*)$ {
        auth_basic "Restricted";
        auth_basic_user_file /etc/nginx/tass/htpasswd;
        proxy_pass http://###.###.#.##:8282/$1;
}
```

Once you have saved and exited the configuration, you need to reload the NGINX server:

```
sudo systemctl reload nginx
```

## Update Device Settings

Now you need to update the device settings using the credentials provided in the HIAS UI. If you changed the Stream Port and Socket Port settings you should also update them in this configuration file.

```
sudo nano confs.json
```
```
{
    "iotJumpWay": {
        "host": "",
        "port": 8883,
        "ip": "localhost",
        "lid": 0,
        "zid": 0,
        "did": 0,
        "dn": "",
        "un": "",
        "pw": ""
    },
    "EMAR": {
        "ip": ""
    },
    "Realsense": {
        "server": {
            "port": 8282
        },
        "socket": {
            "port": 8383
        }
    },
    "MobileNetSSD": {
        "bin": "Model/MobileNetSSD_deploy.bin",
        "classes": [
            "background",
            "aeroplane",
            "bicycle",
            "bird",
            "boat",
            "bottle",
            "bus",
            "car",
            "cat",
            "chair",
            "cow",
            "diningtable",
            "dog",
            "horse",
            "motorbike",
            "person",
            "pottedplant",
            "sheep",
            "sofa",
            "train",
            "tvmonitor"
        ],
        "inScaleFactor": 0.007843,
        "meanVal": 127.53,
        "size": 300,
        "threshold": 0.6,
        "xml": "Model/MobileNetSSD_deploy.xml"
    }
}
```

## Intel® RealSense™ D415
Raspberry Pi 4 Pinout

Now we will install the software for the Intel® RealSense™ D415.

**MAKE SURE YOUR REALSENSE IS NOT PLUGGED IN**

After unsuccessfully following a number of Intel's tutorials to install Realsense on a Raspberry Pi 3 and Raspberry Pi 4 and multiple OS, I was finally pointed in the direction of the [LibUVC-backend installation](https://github.com/IntelRealSense/librealsense/blob/master/doc/libuvc_installation.md "LibUVC-backend installation"). To make this work for our project, you need to modify the downloaded **libuvc_installation.sh** file and carry out an extra step. 

As per the guide, download the file first with:

```
wget https://github.com/IntelRealSense/librealsense/raw/master/scripts/libuvc_installation.sh
```

Then modify:

```
cmake ../ -DFORCE_LIBUVC=true -DCMAKE_BUILD_TYPE=release
```

To:

```
cmake ../ -DFORCE_LIBUVC=true -DCMAKE_BUILD_TYPE=release DBUILD_PYTHON_BINDINGS=bool:true
```

This will install the Python bindings we need to run **PyRealsense**. Now continue with:

```
chmod +x ./libuvc_installation.sh
./libuvc_installation.sh
```

And finally open your **bashrc** file

```
sudo nano ~/.bashrc
```

And add the following to the end of the file before saving and closing. 

```
export PYTHONPATH=$PYTHONPATH:/usr/local/lib
```

You can now plug in your Realsense to the Raspberry Pi and test by using the following to check if your device is recognized and opens successfully:

```
rs-enumerate-devices
```

And finally the following to test that PyRealsense is working:

```
python3
import pyrealsense
exit()
```

If you don't get any errors from **import pyrealsense**, everything is setup correctly for your Realsense.

## Intel® Distribution of OpenVINO™ Toolkit

Again the official Intel tutorials failed in one way or another, I finally came across a very good tutorial on [PyImageSearch](https://www.pyimagesearch.com/2019/04/08/openvino-opencv-and-movidius-ncs-on-the-raspberry-pi/ "PyImageSearch"). The following guide uses the parts relevant to our project and allows you to quickly setup OpenVINO on your Raspberry 4.

```
sudo apt-get install build-essential cmake unzip pkg-config
sudo apt-get install libjpeg-dev libpng-dev libtiff-dev
sudo apt-get install libavcodec-dev libavformat-dev libswscale-dev libv4l-dev
sudo apt-get install libxvidcore-dev libx264-dev
sudo apt-get install libgtk-3-dev
sudo apt-get install libcanberra-gtk*
sudo apt-get install libatlas-base-dev gfortran
sudo apt-get install python3-dev
cd
wget https://download.01.org/opencv/2020/openvinotoolkit/2020.1/l_openvino_toolkit_runtime_raspbian_p_2020.1.023.tgz
tar -xf l_openvino_toolkit_runtime_raspbian_p_2020.1.023.tgz
mv l_openvino_toolkit_runtime_raspbian_p_2020.1.023 openvino
nano ~/.bashrc
```

Now add the following line to the bottom of your bashrc file before saving and closing.

```
source ~/openvino/bin/setupvars.sh
```

## Intel® Neural Compute Stick 2

Again we use instructions provided in the [PyImageSearch](https://www.pyimagesearch.com/2019/04/08/openvino-opencv-and-movidius-ncs-on-the-raspberry-pi/ "PyImageSearch") tutorial to install NCS2 on the Raspberry Pi.

```
sudo usermod -a -G users "$(whoami)"
cd
sh openvino/install_dependencies/install_NCS_udev_rules.sh
```

## Connect the neck
Connect the neck

First of all, push your final servo through the top of **Body-Middle.stl** and screw it in place. Next screw the servo arm to the bottom of the neck and attach to the servo. You may need some glue to keep this part secure.

## Assemble the head
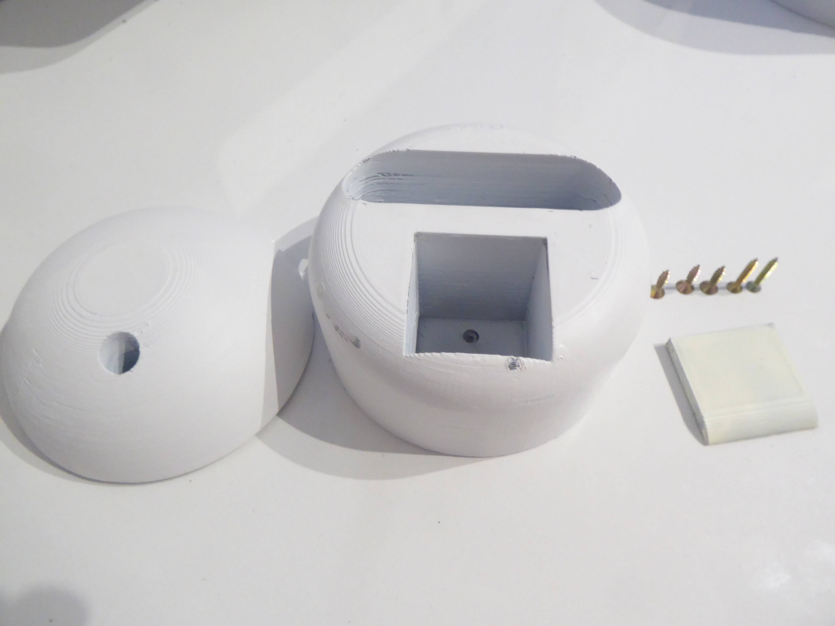
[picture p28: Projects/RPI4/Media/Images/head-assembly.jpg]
Assemble the head


Next let's assemble the head, **Face.stl**, **Head-Back.stl**  and **Camera-Cover.stl**. In the face you will see 3 holes. Use these holes to screw the face onto the back of the head, then place the camera cover over the large sqaure hole on the face.

Assemble the head

## Connect the head to the neck
Connect the neck

Now you need to use the two screws on the side of the neck to attach the head. Start off by screwing the screws just enough that they are coming through the other side, then place the head inside the neck and continue with screwing until the head is attached. 

## Raspberry Pi 4 Stand
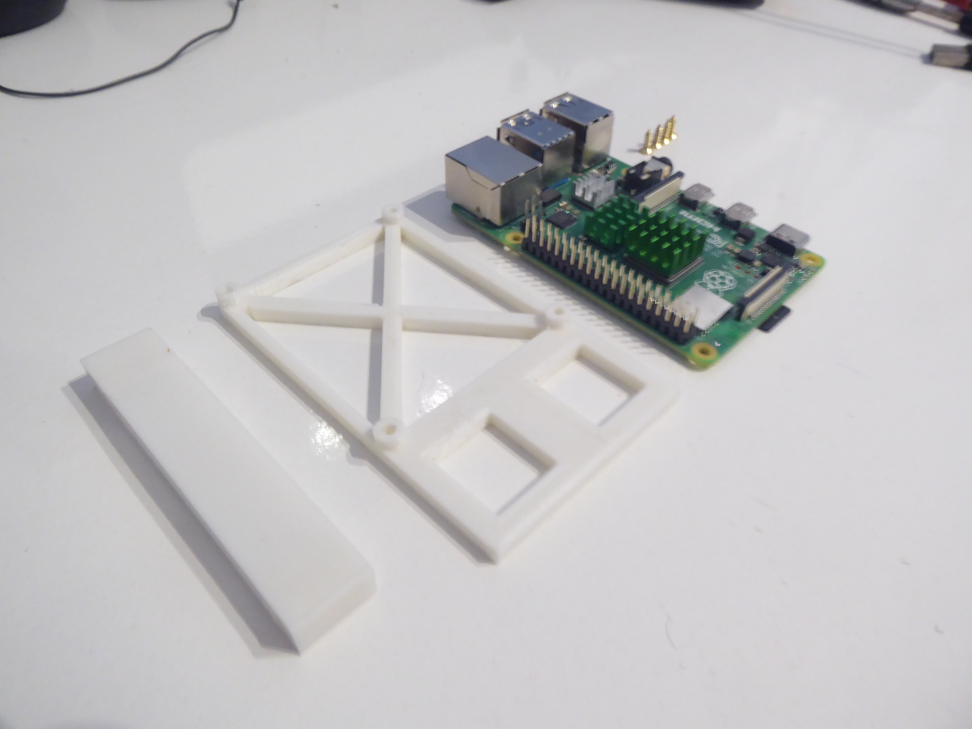
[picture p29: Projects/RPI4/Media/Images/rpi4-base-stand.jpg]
Raspberry Pi 4 Stand


Now we will set up your Raspberry Pi 4 stand that keep the Raspberry Pi in an upright position inside EMAR Mini. 

The related files are **RPI4-Base.stl** and **RPI4-Stand.stl**. First of all slide the stand into the base.

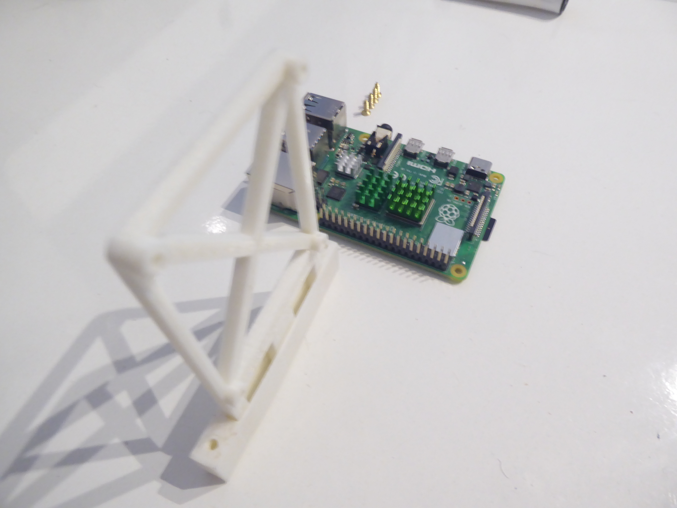
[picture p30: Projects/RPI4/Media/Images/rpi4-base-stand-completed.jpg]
Raspberry Pi 4 Stand


Now screw your Raspberry Pi 4 onto the stand with the ports facing the top.

Raspberry Pi 4 Stand

## Raspberry Pi 4 Pinout
Raspberry Pi 4 Pinout

[Source](https://www.raspberrypi.org/documentation/usage/gpio/ "Source") 

## Breadboard
Breadboard

We will use a breadboard for our circuit. The first step is to connect wires from the PWM pins of the Raspberry Pi 4. Using the Raspberry Pi pinout diagram, connect GPIO 18, 13 and 12 to the breadboard. 

The servo's PWM signal wire is orange, in the photo above we use orange male->male jumper wires to connect the PWM pins to the breadboard. 

Also add a red wire from the 5v power pin and a black wire from ground. but do not connect them yet. 

## Add the Intel® Neural Compute Stick 2
Add the Intel® Neural Compute Stick 2

Now plug your Neural Compute Stick 2 to the top USB3 on your Raspberry Pi.

## Attach Raspberry Pi 4 Stand to EMAR Mini

On the bottom of **Body-Bottom.stl**, you will see two holes for the screws that will attach the Raspberry Pi 4 Stand to the inside of EMAR Mini. 

Attach Raspberry Pi 4 Stand to EMAR Mini

Start by screwing in the screws until they just come throug the other side, this will make it easier to screw in the stand. Then turn the body bottom on it's side and screw in the Raspberry Pi 4 stand. 

Attach Raspberry Pi 4 Stand to EMAR Mini

Turn the bottom the right way up and place the breadboard perched on the top of the body.

## Connect the arm sections
Connect the arm sections

There are two sections to EMAR Mini's arm, **Arm-Section-1.stl** and **Arm-Section-2.stl**. 

Connect the second arm section to the first using one of your servos, and then connect the firt arm section to the body using a second servo, then feed the wires through the hole to the inside of the body. 

## Connect servo wires to breadboard
Connect the arm sections

Now you will connect the three servos to the bread board. Turn the body on it's side and place it close to the bottom of the body so that the wires can reach the breadboard which you left perched on top. 

Next we use red male->male jumpers to connect the servo power wires to the power rail on the breadboard, and male->male brown wires to connect the servo ground wires to ground rail on the breadboard.

Now we will connect the PWM signal wires (orange) to the breadboard. You need to connect them in the following way.

- Head servo -> GPIO 18
- First arm section servo -> GPIO 12
- Secon arm section servo -> GPIO 13

Next connect the red power cable from the Raspberry Pi 4 to the power rail on the breadboard and then the ground cable to the ground rail. 

## Install the breadboard
Install the breadboard

Now you need to gently place the breadboard inside the body of EMAR, just infront of the Raspberry Pi at the bottom. It will be easier to do this if you life the body up as you are placing the breadboard inside.

## Install the Realsense camera
Install the Realsense camera 

Next take the USB type C lead coming from the Realsense camera and place it through the hole at the back of the neck into the body, pull it through and connect it to the second USB3 port on the Raspberry Pi. 

## Finishing up
Finishing up

Now take plug the USB type C power cable into the Raspberry Pi, but do not plug into the mains just yet. 

Once you have done that you need to attach the middle body to the bottom body. Be very careful to make sure you do not pull any of your wires off the Raspberry Pi or the breadboard, and make sure that the USB cable from the Realsense is packed into the top of the body, not doing so could cause you to not be able to move the head.  

Finally push the Realsense camera into the hole in the front of the face and make sure it is secure. In this version there was a miscalculation with the dimensions of the head, it is possible to wedge the camera into the head, but we are working on a larger head design for V2. Make sure the camera is securely wedged into the head before using.

# Continue

Now you can continue back to the [RPI4](../../RPI4 "RPI4") tutorial to complete setup.

&nbsp;

# Contributing

The Peter Moss Acute COVID-19 AI Research project encourages and welcomes code contributions, bug fixes and enhancements from the Github.

Please read the [CONTRIBUTING](../../../CONTRIBUTING.md "CONTRIBUTING") document for a full guide to forking your repositories and submitting your pull requests. You will also find information about your code of conduct on this page.

## Contributors

- [Adam Milton-Barker](https://www.leukemiaresearchassociation.ai/team/adam-milton-barker "Adam Milton-Barker") - [Asociacion De Investigation En Inteligencia Artificial Para La Leucemia Peter Moss](https://www.leukemiaresearchassociation.ai "Asociacion De Investigation En Inteligencia Artificial Para La Leucemia Peter Moss") President & Lead Developer, Sabadell, Spain

- [Jose Mario Garza](https://www.leukemiaresearchassociation.ai/team/jose-mario-garza "Jose Mario Garza") - [Asociacion De Investigation En Inteligencia Artificial Para La Leucemia Peter Moss](https://www.leukemiaresearchassociation.ai "Asociacion De Investigation En Inteligencia Artificial Para La Leucemia Peter Moss") 3D Designer/Printer, Mexico

&nbsp;

# Versioning

You use SemVer for versioning. For the versions available, see [Releases](../../../releases "Releases").

&nbsp;

# License

This project is licensed under the **MIT License** - see the [LICENSE](../../../LICENSE "LICENSE") file for details.

&nbsp;

# Bugs/Issues

You use the [repo issues](../../../issues "repo issues") to track bugs and general requests related to using this project. See [CONTRIBUTING](../../../CONTRIBUTING.md "CONTRIBUTING") for more info on how to submit bugs, feature requests and proposals.

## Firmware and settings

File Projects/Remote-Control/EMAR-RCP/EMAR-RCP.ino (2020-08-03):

/*
  Project:       Peter Moss COVID-19 AI Research Project
  Repository:    EMAR Mini, Emergency Assistance Robot

  Author:        Adam Milton-Barker (AdamMiltonBarker.com)
  Contributors:
  Title:         EMAR Mini Remote Control iotJumpWay Publisher
  Description:   The EMAR Mini Remote Control iotJumpWay Publisher 
                 receives IR commands from the Remote Control Receiver 
                 via serial and sends them to the iotJumpWay.
  License:       MIT License
  Last Modified: 2020-07-04
  Credit: Based on example code from www.elegoo.com
*/

#include <ArduinoJson.h>
#include <ESP8266WiFi.h>
#include <PubSubClient.h>
#include <WiFiClientSecure.h> 

static const char hias_cert[] PROGMEM = R"EOF(
-----BEGIN CERTIFICATE-----
-----END CERTIFICATE-----
)EOF";

const char fingerprint[] PROGMEM = "";

const char* ssid = "";
const char* password = "";

const char* mqtt_server = "";
int mqttPort = 8883;

String locationID = "";
String applicationID = "";
char applicationName[] = ""; 
char mqttUsername[] = ""; 
char mqttPassword[] = ""; 
char willTopic[50];

String zoneID = "";
String deviceID = "";

BearSSL::WiFiClientSecure espClient;
PubSubClient client(espClient);
BearSSL::X509List cert(hias_cert);

char charBuf[50];

void setupWiFi() {
  
  delay(10);
  
  Serial.println();
  Serial.print("Connecting to WiFi network: ");
  Serial.println(ssid);
  
  WiFi.mode(WIFI_STA);
  WiFi.begin(ssid, password);
  
  while (WiFi.status() != WL_CONNECTED) {
    delay(500);
    Serial.print(".");
  }
  
  Serial.println("");
  Serial.println("WiFi connected succesfully!");
  Serial.print("Device IP address: ");
  Serial.println(WiFi.localIP());
  
}

void callback(char* topic, byte* payload, unsigned int length) {
  
  Serial.println("Unused");
  
}

void publishToApplicationStatus(const char* data){
  String statusTopic = locationID+"/Applications/"+applicationID+"/Status";
  statusTopic.toCharArray(charBuf, 50);
  client.publish(charBuf, data);
}

void publishToDeviceCommands(const char* data){
  String commandTopic = locationID+"/Devices/"+zoneID+"/"+deviceID+"/Commands";
  commandTopic.toCharArray(charBuf, 50);
  client.publish(charBuf, data);
}

void reconnect() {
  while (!client.connected()) {
    
    Serial.println("Attempting connection to HIAS iotJumpWay Broker...");
    
    String willTopicString = locationID+"/Applications/"+applicationID+"/Status";
    willTopicString.toCharArray(willTopic, 50);
    
    if (client.connect(applicationName, mqttUsername, mqttPassword, willTopic, 0, 0, "OFFLINE")) {
      Serial.println("Connected to HIAS iotJumpWay Broker!");
      publishToApplicationStatus("ONLINE");
    } else {
      Serial.print("Failed to connect to HIAS iotJumpWay Broker, rc=");
      Serial.println(client.state());
      Serial.println("... trying again in 5 seconds");
      delay(5000);
    }
    
  }
}

void setup() {
  
  Serial.begin(9600);
  
  setupWiFi();
  //espClient.setTrustAnchors(&cert);
  espClient.setFingerprint(fingerprint);
  client.setServer(mqtt_server, mqttPort);
  client.setCallback(callback);
}

void loop() {
  
  if (!client.connected()) {
    reconnect();
  }
  client.loop();
  
  while (Serial.available() > 0)
  {
    String jsReceived = Serial.readStringUntil('\n');

    StaticJsonDocument<200> jsonBuffer;
    auto error = deserializeJson(jsonBuffer, jsReceived);
    if(error)
    {
      Serial.println("Command Not Sent");
    }
    else
    {
      char jsData[89];
      jsReceived.toCharArray(jsData, 89);
      publishToDeviceCommands(jsData);
      Serial.println("Command Sent");
    }
  }
  
  delay(1000);
}

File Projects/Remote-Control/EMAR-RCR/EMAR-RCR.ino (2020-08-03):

/*
  Project:       Peter Moss COVID-19 AI Research Project
  Repository:    EMAR Mini, Emergency Assistance Robot

  Author:        Adam Milton-Barker (AdamMiltonBarker.com)
  Contributors:
  Title:         EMAR Mini Remote Control Receiver
  Description:   The EMAR Mini Remote Control Receiver receives 
                 IR commands and sends them to the iotJumpWay via
                 the EMAR Mini Remote Control iotJumpWay Publisher.
  License:       MIT License
  Last Modified: 2020-07-13
  Credit: Based on example code from www.elegoo.com
*/

#include <ArduinoJson.h>
#include "IRremote.h"
#include "IR.h"

IRrecv irrecv(RECEIVER);
decode_results results;

String deviceID = "";

void setup() {
  Serial.begin(9600);
  Serial.println("EMAR Mini Remote Control Receiver");
  irrecv.enableIRIn();
}

void send_communication(String cTypeR, String cValR, String cMessageR)
{
  String jsonString = "{\"From\":\""+deviceID+"\",\"Type\":\""+cTypeR+"\",\"Value\": \""+cValR+"\",\"Message\": \""+cMessageR+"\"}";
  char charBuff[89];
  jsonString.toCharArray(charBuff, 89);
  Serial.println(jsonString);
}

void loop()
{
  int tmpValue;
  if (irrecv.decode(&results))
  {
    for (int i = 0; i < 23; i++)
    {
      if ((keyValue[i] == results.value) && (i<KEY_NUM))
      {
        String aVal = keyBuf[i];
        String cType = "";
        String cVal = "";
        String cMessage = "";

        if(aVal=="VOL+")
        {
          cType = "Head";
          cVal = "UP";
          cMessage = "Move Head UP";
          send_communication(cType, cVal, cMessage);
        }
        else if(aVal=="VOL-")
        {
          cType = "Head";
          cVal = "DOWN";
          cMessage = "Move Head DOWN";
          send_communication(cType, cVal, cMessage);
        }
        else if(aVal=="FAST FORWADOWN")
        {
          cType = "Head";
          cVal = "RIGHT";
          cMessage = "Move Head RIGHT";
          send_communication(cType, cVal, cMessage);
        }
        else if(aVal=="FAST BACK")
        {
          cType = "Head";
          cVal = "LEFT";
          cMessage = "Move Head LEFT";
          send_communication(cType, cVal, cMessage);
        }
        else if(aVal=="PAUSE")
        {
          cType = "Head";
          cVal = "CENTER";
          cMessage = "Move Head CENTER";
          send_communication(cType, cVal, cMessage);
        }
        else if(aVal=="UP")
        {
          cType = "Arm";
          cVal = "UP";
          cMessage = "Move Arm 1 UP";
          send_communication(cType, cVal, cMessage);
        }
        else if(aVal=="DOWN")
        {
          cType = "Arm";
          cVal = "DOWN";
          cMessage = "Move Arm 1 DOWN";
          send_communication(cType, cVal, cMessage);
        }
        else if(aVal=="2")
        {
          cType = "Arm";
          cVal = "2UP";
          cMessage = "Move Arm 2 UP";
          send_communication(cType, cVal, cMessage);
        }
        else if(aVal=="5")
        {
          cType = "Arm";
          cVal = "2DOWN";
          cMessage = "Move Arm 2 DOWN";
          send_communication(cType, cVal, cMessage);
        }
        
        tmpValue = results.value;
        
      }
      else if(REPEAT==i)
      {
        results.value = tmpValue;
      }
    }
    irrecv.resume(); // receive the next value
  }
}

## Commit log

2020-05-26 Full restructure including all 3 devices
2020-05-29 Device restructure and addition of OpenVINO / Neural Compute Stick 2
    Device restructure and addition of OpenVINO / Neural Compute Stick 2
2020-05-29 Fixed device IDs
2020-05-29 Fixed device descriptions
2020-07-09 STLs For 3D Printing project added
    [Arm-Section-1.stl, Arm-Section-2.stl, Body-Bottom.stl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]
2020-08-03 Updated to current branch 0.4.0 and dev branch 0.5.0
